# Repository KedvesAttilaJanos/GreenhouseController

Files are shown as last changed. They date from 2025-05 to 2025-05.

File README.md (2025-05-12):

# 🌱 Smart Greenhouse Controller (IoT Project)

📄 This README is available in multiple languages:
🇭🇺 [Magyarul itt olvasható »](docs/README.hu.md)

This project is a smart greenhouse controller built with Arduino and ESP8266 for monitoring and controlling various environmental factors in a greenhouse. The system collects data from multiple sensors and can be monitored remotely via a web interface.

## Features
- **Sensors:**
  - DHT11 – Temperature and Humidity Sensor
  - Soil Moisture Sensor (Analog output)
  - Light Sensor (LDR)
- **ESP8266 WiFi Module** – Enables remote monitoring via a web page.
- **OLED Display** – Displays real-time data on temperature, humidity, soil moisture, and light intensity.
- **Joystick** – Allows manual control for adjusting parameters such as watering or fan speed.
- **Future Plans** – Adding CO2 monitoring capabilities.

📄 Documentation
The full project documentation is available in two languages (Hungarian and English) in the /docs folder. It includes hardware schematics, system overview, and usage instructions.

## Components
- **Microcontroller:**
  - Arduino (for sensor data processing and control)
  - ESP8266 (for WiFi and web server)
  
- **Sensors:**
  - DHT11 – For temperature and humidity measurement
  - Soil Moisture Sensor – For soil moisture monitoring
  - Light Sensor (LDR) – For light intensity measurement
  
- **Display:**
  - OLED SSD1306 – For displaying sensor data
  
- **Joystick:**
  - Two-axis analog joystick for manual input
  
- **Libraries:**
  - `#include <SPI.h>` – For SPI communication
  - `#include <Wire.h>` – For I2C communication
  - `#include <Adafruit_GFX.h>` – For graphics on the display
  - `#include <dht.h>` – For DHT11/DHT22 sensor handling

## PCB and Schematics
The project includes a custom PCB designed for the greenhouse controller. You can find the PCB files and the circuit schematic below:
- **PCB Files**: The PCB layout files (Gerber) can be found in the `/hardware/` folder.
- **Schematic Diagram**: The circuit schematic for the project is available as [PDF](docs/Schematic.pdf) [SVG](docs/Schematic.svg).

**Wiring and Assembly**:
- The wiring diagram is available under `/docs/wiring_diagram.png`, which illustrates how to connect the sensors and the microcontroller.

## 3D Printed Case
The project includes a 3D printed case to house the controller and sensors. This case helps protect the electronics and provides a clean and durable solution for mounting the components.

- **3D Printing Files**: The STL files for the 3D printed case can be found in the `/3d_case/` folder.
- You can print the case using any 3D printer.
- **Print Settings**: The recommended print settings are:
  - Layer height: 0.2mm
  - Infill: 20-30%
  - Material: PLA or ABS

## Setup and Installation
1. **Install Arduino IDE**: If you haven’t already, install the [Arduino IDE](https://www.arduino.cc/en/software).
2. **Install Libraries**: 
   - Adafruit GFX: `Sketch > Include Library > Manage Libraries > Adafruit GFX`
   - DHT Sensor Library: `Sketch > Include Library > Manage Libraries > DHT sensor library`
   
3. **Wiring**:
   - Connect your sensors to the Arduino as per the wiring diagram. You can find the wiring diagram under `/docs/wiring_diagram.png`.

4. **Upload Code**:
   - Upload the code from `firmware/SmartGreenhouse.ino` to your Arduino using the Arduino IDE.

## Future Work
1. **Integration of Additional Modules**
    Add CO2 sensor to monitor air quality.
    Add I2C clock module, for time based irrigation

2. **Memory Optimization**  
   The system currently operates with redundant, repeated text outputs, such as on the OLED display. These text strings should be organized into static character arrays or `const char*` variables, reducing SRAM usage.

3. **Eliminating AT Commands**  
   The ESP8266 is currently controlled via AT commands, which is not the most efficient approach. Instead of using the AT firmware, it would be better to use the NodeMCU (Lua) or the ESP8266 Arduino core, programming the microcontroller directly. This would remove the need for AT commands over the serial connection, allowing the ESP8266 to handle the control directly, while the Arduino Mega only transmits sensor data. This improves response time, reduces the chance of errors, and opens up further possibilities (e.g., HTTPS connections, JSON handling). Right now, when the controller is communicating, the hardware interface is freezd for a sec.

4. **External Network Accessibility**  
   The system is currently only accessible on the local network. A future development could involve making the web interface accessible over the internet.

5. **Data Security and Encryption**  
   The transmitted data is likely unencrypted over the network, making encryption a critical feature to implement.

6. **Fault Tolerance and Diagnostics**  
   Implementing a basic fault-tolerant system would be useful, such as using a watchdog (same used in the restart method) timer that restarts the system if it freezes or if no data is received within a certain time period. A logging feature for save errors or key events to an SD card.
## License
This project is licensed under the [MIT License](LICENSE).
You are free to use, modify, and distribute this code, even in commercial projects, as long as you include the original license and credit the author.

## Contact
If you have any questions or suggestions, feel free to contact me at:  
ata.kedves@gmail.com

---

🌱 Happy gardening with your smart greenhouse!

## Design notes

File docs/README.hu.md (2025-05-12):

# 🌱 Okos Melegház Vezérlő (IoT Projekt)

Ez a projekt egy okos melegház vezérlő, amely Arduino és ESP8266 alapú, a különböző környezeti tényezők monitorozására és vezérlésére a melegházban. A rendszer több szenzortól gyűjt adatokat, és távolról, egy webes felületen keresztül figyelhető.

## Jellemzők
- **Szenzorok:**
  - DHT11 – Hőmérséklet- és páratartalom mérő
  - Talajnedvesség szenzor (analóg kimenet)
  - Fényérzékelő (LDR)
- **ESP8266 WiFi Modul** – Távoli monitorozás weboldalon keresztül.
- **OLED Képernyő** – Valós idejű adatok megjelenítése hőmérsékletről, páratartalomról, talajnedvességről és fényintenzitásról.
- **Joystick** – Manuális vezérlés a paraméterek, például öntözés vagy ventilátor sebességének beállításához.
- **Jövőbeli terveink** – CO2 monitorozási képességek hozzáadása.

📄 Dokumentáció  
A teljes projekt dokumentációja két nyelven (magyar és angol) elérhető a /docs mappában. Tartalmazza a hardver áramköri terveit, a rendszer áttekintését és a használati utasításokat.

## Alkatrészek
- **Mikrokontroller:**
  - Arduino (a szenzoradatok feldolgozásához és vezérléshez)
  - ESP8266 (WiFi és web szerverhez)

- **Szenzorok:**
  - DHT11 – A hőmérséklet és páratartalom méréséhez
  - Talajnedvesség szenzor – A talajnedvesség méréséhez
  - Fényérzékelő (LDR) – A fényintenzitás méréséhez

- **Képernyő:**
  - OLED SSD1306 – A szenzoradatok megjelenítéséhez

- **Joystick:**
  - Két tengelyes analóg joystick a manuális bemenethez

- **Könyvtárak:**
  - `#include <SPI.h>` – SPI kommunikációhoz
  - `#include <Wire.h>` – I2C kommunikációhoz
  - `#include <Adafruit_GFX.h>` – A képernyőn történő grafika megjelenítéséhez
  - `#include <dht.h>` – DHT11/DHT22 szenzor kezeléséhez

## PCB és Áramköri Tervek
A projekt tartalmaz egy egyedi PCB-t a melegház vezérlő számára. Az alábbiakban találhatóak a PCB fájlok és az áramköri terv:
- **PCB fájlok**: A PCB elrendezési fájlok (Gerber) a `/hardware/` mappában találhatók.
- **Áramköri diagram**: Az áramköri terv PDF formátumban elérhető: [PDF](Schematic.pdf) [SVG](Schematic.svg).

**Vezetékek és összeszerelés:**
- A vezetékek diagramja elérhető a `/docs/wiring_diagram.png` alatt, amely bemutatja, hogyan kell csatlakoztatni a szenzorokat és a mikrokontrollert.

## 3D Nyomtatott Tok
A projekt tartalmaz egy 3D nyomtatott tokot a vezérlő és a szenzorok elhelyezésére. Ez a tok segít megvédeni az elektronikát, és tiszta, tartós megoldást biztosít az alkatrészek felszereléséhez.

- **3D Nyomtatás Fájlok**: A 3D nyomtatott tok STL fájljai a `/3d_case/` mappában találhatók.
- A tok bármilyen 3D nyomtatóval kinyomtatható.
- **Nyomtatási beállítások**: A javasolt nyomtatási beállítások:
  - Rétegmagasság: 0.2mm
  - Kitöltés: 20-30%
  - Anyag: PLA vagy ABS

## Beállítás és Telepítés
1. **Arduino IDE telepítése**: Ha még nem tetted meg, telepítsd az [Arduino IDE-t](https://www.arduino.cc/en/software).
2. **Könyvtárak telepítése**: 
   - Adafruit GFX: `Sketch > Include Library > Manage Libraries > Adafruit GFX`
   - DHT szenzor könyvtár: `Sketch > Include Library > Manage Libraries > DHT sensor library`
   
3. **Vezetékek csatlakoztatása**:
   - Csatlakoztasd a szenzorokat az Arduinohoz a vezeték diagram szerint. A vezeték diagramot a `/docs/wiring_diagram.png` alatt találod.

4. **Kód feltöltése**:
   - Töltsd fel a kódot a `firmware/SmartGreenhouse.ino` fájlból az Arduino IDE segítségével.

## Jövőbeli Munka
1. **További modulok integrálása**
   CO2 szenzor hozzáadása a levegőminőség monitorozásához.
   I2C óra modul hozzáadása, idő alapú öntözéshez.

2. **Memória optimalizálás**  
   A rendszer jelenleg redundáns, ismétlődő szövegeket jelenít meg, például az OLED kijelzőn. Ezeket a szövegeket statikus karakter tömbökké vagy `const char*` változókká kell szervezni, csökkentve ezzel a SRAM használatot.

3. **AT parancsok eltávolítása**  
   Az ESP8266 jelenleg AT parancsokkal van vezérelve, ami nem a leghatékonyabb megoldás. Az AT firmware helyett jobb lenne a NodeMCU (Lua) vagy az ESP8266 Arduino alapú rendszer használata, közvetlenül a mikrokontroller programozásával. Ez eltávolítaná az AT parancsokat a soros kapcsolatról, lehetővé téve az ESP8266 számára, hogy közvetlenül végezze el a vezérlést, miközben az Arduino Mega csak az adatokat küldi. Ez javítja a válaszidőt, csökkenti a hibák lehetőségét, és további lehetőségeket nyit meg (pl. HTTPS kapcsolatok, JSON kezelés). Jelenleg, amikor a vezérlő kommunikál, a hardver interfész egy pillanatra lefagy.

4. **Külső hálózati elérhetőség**  
   A rendszer jelenleg csak a helyi hálózaton érhető el. A jövőben a webes felületet elérhetővé lehetne tenni az interneten.

5. **Adatbiztonság és titkosítás**  
   Az átadott adatok valószínűleg titkosítatlanok a hálózaton, így a titkosítás kritikus funkció lenne a megvalósítás során.

6. **Hibakeresés és diagnosztika**  
   Hasznos lenne egy alapvető hibatűrő rendszer bevezetése, például egy figyelő (watchdog) időzítő alkalmazása, amely újraindítja a rendszert, ha az lefagy, vagy ha egy meghatározott időn belül nem érkezik adat. Egy naplózó funkció, amely tárolja a hibákat vagy fontos eseményeket SD kártyán.

## Licenc
Ez a projekt a [MIT Licenc](/LICENSE) alatt van licencelve.  
Szabadon használhatod, módosíthatod és terjesztheted a kódot, még kereskedelmi projektekben is, amennyiben tartalmazza az eredeti licencet és tiszteletben tartja a szerző jogait.

## Kapcsolat
Ha bárminemű kérdésed vagy javaslatod van, bátran kereshetsz:
ata.kedves@gmail.com

---

🌱 Boldog kertészkedést az okos melegházaddal!

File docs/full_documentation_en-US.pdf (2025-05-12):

# Liceul Teoretic "Ernő Solomon" Gheorgheni

# Lucrare de atestat disciplina INFORMATICĂ

Profesor coordonator: | Elev:
Zoltán Csíki | Dear Attila-János

# Gheorgheni

2025

Subscribe to DeepL Pro to translate larger documents. Visit www.DeepL.com/pro (https://www.deepl.com/pro?cta=edit-document&pdf=1) for more information.

# Smart Greenhouse Controller

# -IoT project/Automated system-

## Content

# Introduction

### While thinking about my exam paper, I had several different project ideas. But I was sure that what I wanted to do should be useful and of some value. I wanted to create something that was not only interesting for me, but that could be used by

anyone else.

Automation is a technology that has been around for a long time, but I think that it is not available to everyone and that few people use it, especially in the agricultural sector, where it is possible to achieve great productivity results with simple automation. But if automation can be so useful, the question arises why it is not widespread. I think this question arises because these technologies are not explicitly available to individuals and only big-boned agricultural companies can

afford such improvements. In my view, open source projects can provide a solution.

### This will make it easier to bring the technology to users who have not had access to it

before.

### IoT, short for "Internet of things", is the English acronym for the Internet of

things. It short for a variety of electronic devices that can detect, possibly process, some essential information and communicate with another device on the network.

### This explains why it is important for an automated controller to belong to this IoT group. One of the main features of a greenhouse controller is that it can control the

current parameters even in the absence of the user, something an IoT device can do.

The main value of this system lies in the processing of sensory values. I designed it to be able to measure all the parameters that characterise a greenhouse. I considered humidity, temperature, ground humidity and light intensity to be less important, but I left the measurement of carbon dioxide levels as an extensible function. I considered it important to study the external temperature and humidity to

track how environmental factors affect the internal condition of the greenhouse.

### In addition to web-based management, it is important that the functions can be seen and modified on the spot. Monitoring is made possible by a 0.96 inch oled

display,

### which displays the data broken down into menu items. A joystick module allows you

to make changes.

### Of course, in addition to processing and managing data, it is essential to actively and artificially influence the internal environment. This is done by a 6-

channel relay module that switches on and off the light supply, humidification, irrigation and fan status.

### Ultimately, I think it is important to create automation systems that are

accessible to a wide range of users, both individuals and small businesses.

### Furthermore, it is also important that such an automation system is open source, so

that it can be understood by everyone and can be further developed in the future.

### From this point of view, I would like to recall an idea of Linus Torvalds: "Intelligence comes from the ability of people to use and develop the ideas of others."

# Development opportunities

The current greenhouse control system successfully implements the basic functions in many respects, such as temperature and humidity measurement and display on an OLED display, and the transmission of sensor data to an internal network server via the ESP8266 module. At the same time, the system can be further developed and optimised in several ways that not only increase performance, but also

significantly improve system reliability and functionality.

1. Memory optimisation In its current state, the system operates with redundant, repetitive text in several places, for example when writing to the OLED display. These text strings should be organized in static character arrays or in #define or const char* variables to reduce the load on SRAM. In addition, it is recommended to use C-style char[] arrays

instead of the String type, as the String type may fragment memory during long runs.

### 2. Omission of AT commands The ESP8266 is currently probably controlled via AT commands, which is not the most efficient solution. Instead of AT firmware, it is recommended to NodeMCU (Lua) or the ESP8266 Arduino core, and the microcontroller

### direct programming. This way, you don't need to send AT commands over a serial connection, but the ESP8266 itself takes control and the Arduino Mega only transmits sensor data. This increases response time, reduces error possibilities and extends the

possibilities (e.g. HTTPS connection, JSON handling).

### 3. Accessibility from an external network The system is currently only available on the internal network. A next development step could be to make the web interface available via the Internet. This can be achieved by using dynamic DNS (DDNS), port forwarding in the router, or - as

a more secure and scalable solution - by sending data to a cloud-based server (e.g.

### using MQTT, HTTPS POST REST API). The data can even be displayed in a real-

time web dashboard, e.g. Node-RED.

4. Data security and encryption Currently, the data being transmitted is likely to travel unencrypted over the network, so an important development is the introduction of encrypted data communication. This could be done using HTTPS or lower level AES encryption (either Arduino side encryption, server side decryption). This is particularly important

if the device is connected to the internet or would handle sensitive data in the future.

5. Modular and reusable code By structuring the project further, a more general, easily reusable code base can be created. It is advisable to organise the handling of individual hardware elements into separate classes or function groups (e.g. SHT sensor handler, display controller, network communication module). This not only makes the code more readable and maintainable, but also prepares the project for future expansion into a

multi-module system (e.g. multi-zone greenhouse).

### 6. Fault tolerance and diagnostics It would be useful to have a basic fault-tolerant system, for example using a watchdog timer, which restarts the system if it freezes or if no data is received for a certain period of time. In addition, a logging facility that saves errors or major events

to an SD card or the cloud is useful.

# Development environment

# Arduino IDE 2.0

### Programming an Arduino, like most programming languages, uses what is called an Integrated Development Environment, or IDE. An integrated development environment (IDE) is a software application that provides computer programmers with comprehensive facilities for software development. An IDE usually

consists of at least a source code editor, automation tools and a debugger.

### There are several IDEs to choose from for programming the arduino. Arduino officially offers two different Arduino IDEs for developers: Arduino IDE 1.x - This is the classic version, which was the default development

environment for a long time. It is simple, fast, and widely supported.

### Arduino IDE 2.x - The next generation Arduino IDE, offering a modern user interface, advanced editing features (e.g. auto-complete code, dark mode) and

improved debugging capabilities.

### I have chosen to develop with Arduino IDE 2.0, as this version provides a

more developer-friendly environment.

### This IDE provides easy debugging possibilities. A so-called serial monitor is available, which allows you to keep track of variables, runtime, and correct function

calls. This can be done by a simple Serial.print(Val, Format) line inserted in the code. Val - The data we want to print. It can be a number, string, character or variable.

### Format- This is an optional parameter that specifies the format in which the value

should be displayed.

### Overview of arduino IDE 2

### (1) Error correction (2) Upload, upload the program to for microcontroller (3) Check/debug

### (1.) Managing files in use (2.) Motherboard manager, installing different motherboards (3.) Library manager, installing libraries (4.) Debugging, debugger (5.) Search by keyword in the project

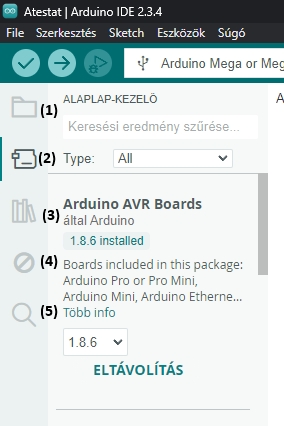
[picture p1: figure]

# Version control

Version management is the management of data with multiple versions.

### Version management systems are most commonly used in engineering and software development to manage versions of documents under development, designs, source code and other data that multiple people are working on simultaneously. Each change

is tracked by version numbers or version letters.

Version Control Systems (VCS) are software tools that allow you to track changes to program code or other digital files over time. During software development, the source code is constantly changing: new features are added, bugs are fixed, or experimental changes are made by developers. A well-functioning version control system allows these changes to be documented and retrieved, and allows multiple developers to work on the same project at the same time without

accidentally overwriting each other's work.

With version management, all changes are logged: who changed what, when and what. This not only makes development more transparent and secure, but also allows you to restore a stable state to a previous state if, for example, a new change causes a bug. Version management not only supports teamwork, but also organises

and archives the work of individual developers.

The best-known and most widely used version control system today is Git,

developed by Linus Torvalds, the creator of the Linux operating system. Git is a distributed version control system, so each developer has the history of the entire project on his own machine. This is particularly useful when you are temporarily disconnected from the Internet or need to back up. The most popular online repository for Git is GitHub, which not only allows version control, but also offers a full community platform where other developers' projects are available and you can

collaborate.

# Libraries

### The development of an efficient and fast

we use different libraries for programming.

The term "library" simply refers to a file that contains compiled object code (and data) that can later be edited (linked) by a program. Libraries allow an application to be more modular, faster to recompile and easier to update. Libraries can be classified into three types: static libraries, shared libraries and dynamic load (DL)

libraries.

### In the Arduino ecosystem, libraries can be installed via the built-in interface and can be included in code with a single #include statement. Each library is used to

support a specific hardware or function, for example.
- #include <Wire.h> - Handles I2C (Inter-Integrated Circuit) communication.

### - #include <Adafruit_GFX.h> - The Adafruit Graphics Library, which draws

graphical objects (text, lines, shapes) on the display.

### - #include <dht.h> - A simple library for managing DHT11/DHT22 temperature and

humidity sensors.

# Tools

### For the project, I used various hardware tools to provide control, data collection and display. These devices work together to implement the functionality of

the system.

## Microcontroller: Arduino and ESP8266

### The project is based on an Arduino Mega, which is responsible for managing the sensors and displays. In addition, the ESP8266 Wi-Fi module allows the system to

connect to a network and send data to a server.

## Arduino Mega

### The Arduino microcontroller processes the sensor data and controls the output

devices.

### The Arduino Mega 2560 is an ATmega2560 microcontroller board. It has 54 digital input and output pins (15 of which can be used as PWM outputs), 16 analog

inputs, 4 UART (hardware serial port), 16 MHz crystal oscillator, USB connector, power connector, ICSP header and reset button.

### Structure of the arduino mega

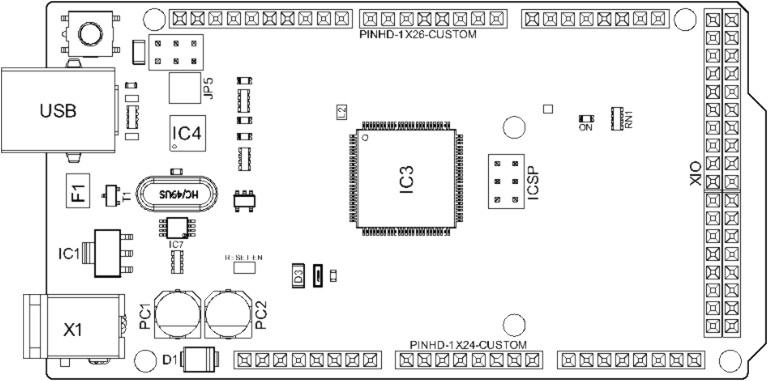
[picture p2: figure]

### Footprint of the arduino mega

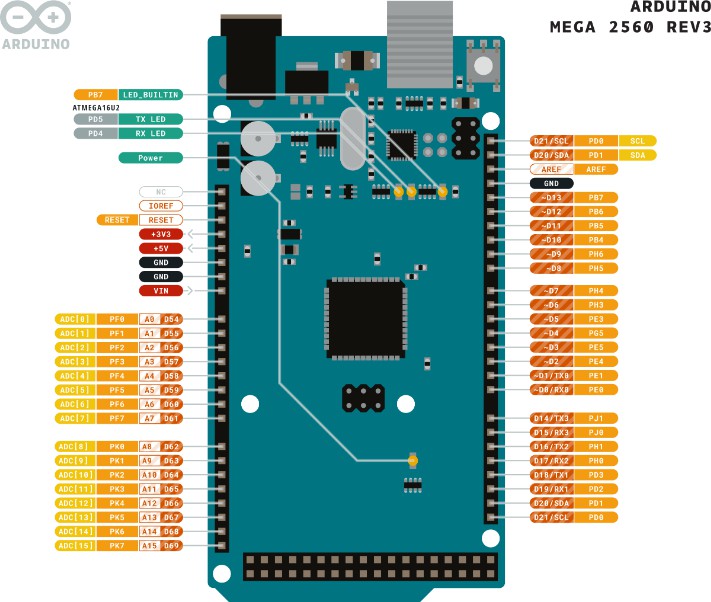
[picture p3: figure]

## ESP8266:

A microcontroller that can also act as a standalone Wi-Fi module,

### communicating with the Arduino via AT commands over a serial connection and

allowing data to be transmitted to the Internet.

The ESP8266 is a very popular, low-cost Wi-Fi enabled microcontroller module developed by Espressif Systems. The module has an integrated TCP/IP protocol stack and a 32-bit RISC CPU that can operate at clock speeds of up to 80-160 MHz. Thanks to its built-in Wi-Fi functionality, it is an ideal choice for IoT (Internet of Things) projects, as it can connect to wireless networks independently or act as a Wi-Fi

modem in addition to another microcontroller.

The ESP-01 has only 8 legs, two of which can be used as GPIO ports (GPIO0, GPIO2), the rest for power, serial communication (TX/RX) and control.
It can be programmed with AT commands via another microcontroller (e.g.

### Arduino UNO) or directly if a suitable USB to serial converter and the appropriate

firmware in the Arduino IDE are available.
The figure below shows the function of the microcontroller's pins (Figure 1) and an example of how to connect it to an arduino mega (Figure 2).

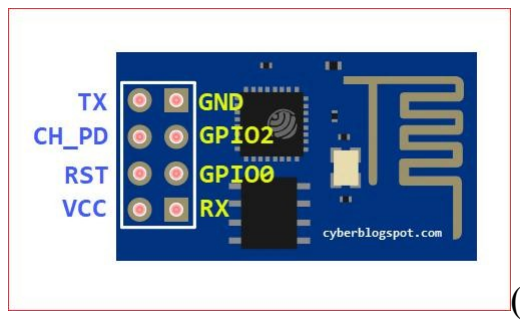
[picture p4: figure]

(Figure 1.)

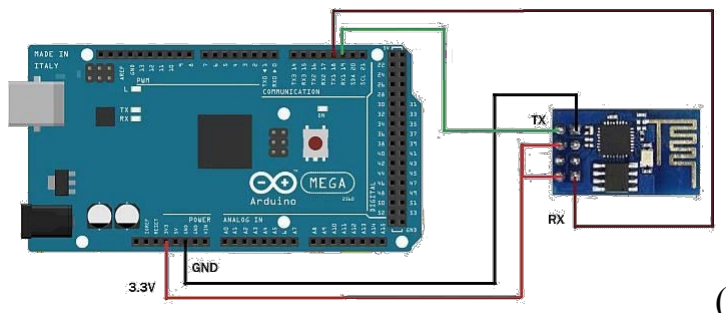
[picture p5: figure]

### (Figure 2,)

## Sensors (sensors)

### To operate the system, I used various sensors that allow the measurement and

processing of environmental data.

### DHT11 - Temperature and humidity sensor

- It allows you to measure air temperature and humidity.
- It provides digital output that can be easily processed by the Arduino.

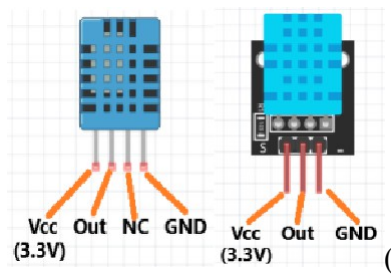
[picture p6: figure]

### (Output of the sensor spikes)

### Soil moisture sensor

### - It measures the soil moisture content, which can help to control

automatic irrigation.

### - It gives an analog output, which can be received by one of the analog pins of the

arduino.

(Function of the sensor spikes)

### Light level detector LDR

- Photo-resistance, the amount of resistance depends on the intensity of the light incident on it.
- The output is read by one of the analog inputs of the arduino.

## Display: OLED SSD1306

### The 0.96-inch OLED display (SSD1306) allows you to visualize the

measured data in menu-driven format.Using the Adafruit SSD1306 and GFX libraries, you can easily plot text and graphical elements (e.g. icons or diagrams).

The SSD1306 type display using OLED (Organic Light Emitting Diode) technology is a low-power, high-contrast display often used in embedded systems such as Arduino or ESP8266 microcontrollers. The most common version of the display is 0.96 inches in diameter, has a resolution of 128x64 pixels, and contains a control chip, SSD1306, which is responsible for driving the OLED matrix. This controller also supports I2C and SPI communication protocols, allowing easy

connectivity and fast data transfer.

### Displays have the advantage of a high brightness, high contrast image, as each pixel light independently, eliminating the need for backlighting. Their small size and low power consumption make them ideal for mobile and IoT applications such as

displaying sensor data or simple menus.

The following figures show the connections needed to communicate with the Arduino. The first figure (Figure 1) shows a connection established with an arduino uno using the I2C communication protocol. The second figure (Figure 2) shows the function of the display spikes (also using I2C communication protocol). The third figure (Figure 3) also shows the function of the spikes, but with a display using SCA

communication.

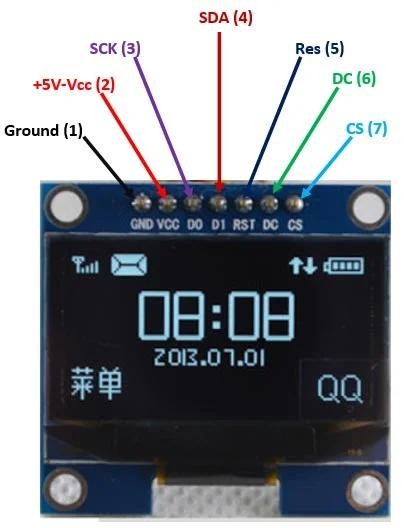
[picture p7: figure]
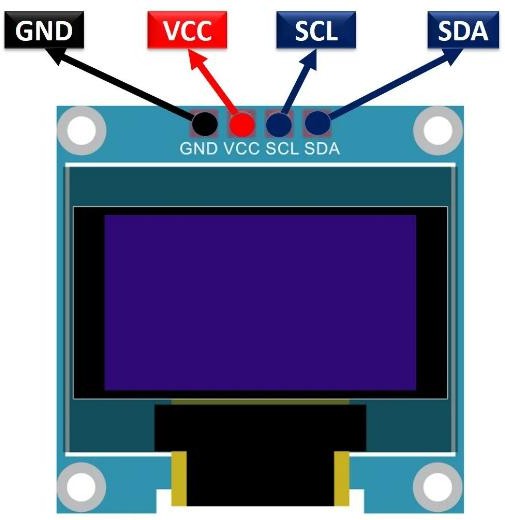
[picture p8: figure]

Figure 3. | Figure 2.

Figure 1.

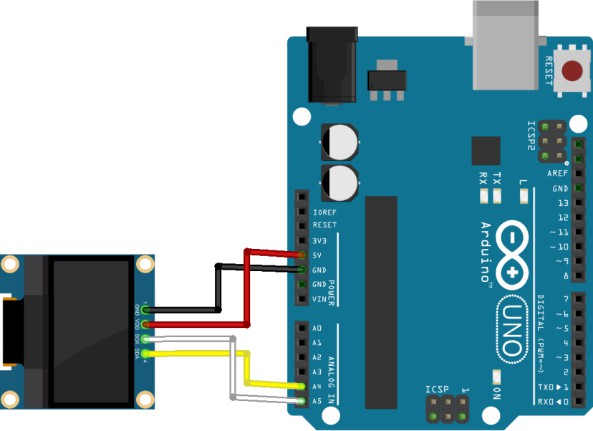
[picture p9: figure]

## Joystick module

## - In this project I use a two-axis analogue joystick module, which allows the

user to provide physical input to the system.

## - This module consists of two potentiometers and a push button, so it can

detect X-Y movement and click.

## The following pictures show the connectors of the module and the values

returned in relation to the displacement.

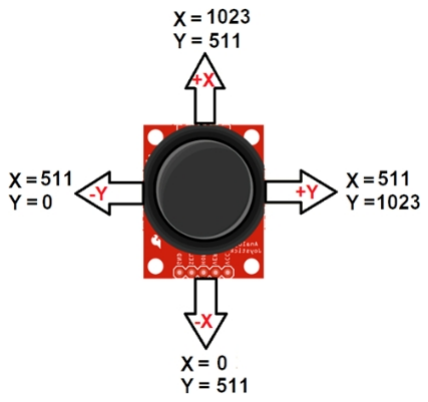
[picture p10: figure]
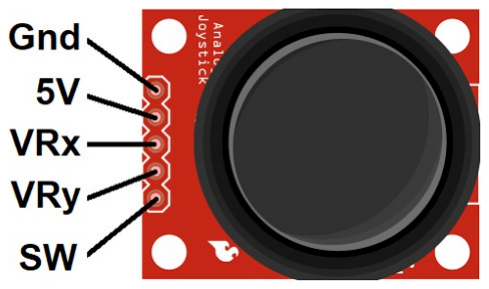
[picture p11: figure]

# Protocols

### In the project, I use different communication protocols to transfer data between devices. These protocols allow sensors, displays and the ESP8266 Wi-Fi

module to communicate with the Arduino.

## 1. I²C (Inter-Integrated Circuit) protocol

- I²C is a serial communication protocol mainly used to connect sensors,

### displays and other peripherals. It is a two-wire system consisting of a clock

line (SCL) and a data line (SDA).

### - I²C is typically used for short-range, relatively low-speed communication between ICs and on-board systems - The I²C (Inter-Integrated Circuit) is a multi-master, multi-slave, packet-switched serial bus developed by Philips Semiconductor (now NXP

Semiconductors).

### - In this project, the I2C protocol is used to communicate with the display, but as a development option it can be extended with an RTC module to monitor

the time in real time.

### Illustration of the I2C protocol

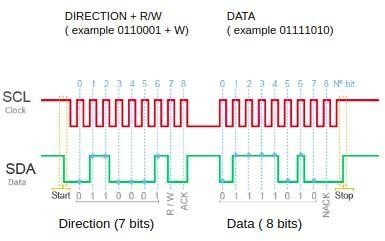
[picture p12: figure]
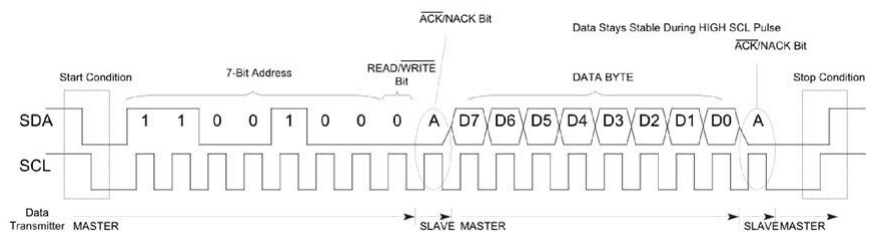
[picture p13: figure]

## 2. UART (Universal Asynchronous Receiver-Transmitter) -

### Soros communication - A universal asynchronous transceiver (UART for short) is a hardware device

that translates between serial and parallel interfaces.

### - The UART protocol is one of the most commonly used communication methods between microcontrollers and external modules. It is based on two wire systems: TX-Transmitter - Transmitter, RX-Receiver - Receiver - In my project the arduino and the esp8266 are connected in series

### The UART protocol diagram

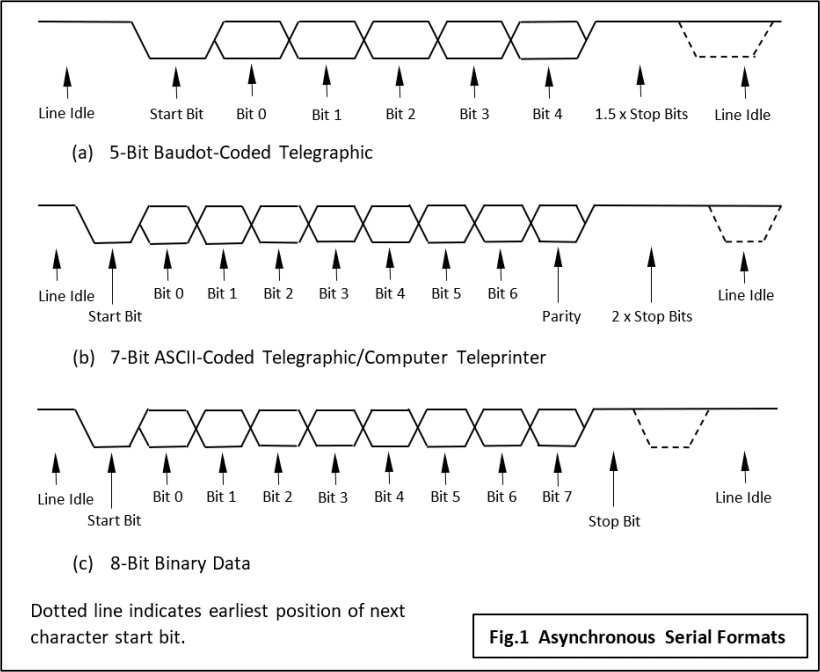
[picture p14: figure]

### 3. AT protocol - The protocol allows a microcontroller or computer to issue instructions to a

device, such as an ESP8266 Wi-Fi module, via serial (UART) communication.

### - AT-Commands (or Hayes AT-Commands) is a standard modem controller command set originally developed by Hayes Microcomputer Products in the 1980s. The abbreviation "AT" is derived from the word "attention", since each command begins with the prefix "AT", indicating to the modem that a

new command is about to follow.

### - Examples of using at commands with esp: - AT+CWJAP="SSID", "PASSWORD" - Connect to Wi-Fi network

(ESP8266).
- Retrieve AT+CIFSR-Ip cim.

### - AT+CIPSTART="TCP","192.168.1.50",8080-szerverhez való

joining.

# Used programming environment

To implement the project I used the Arduino programming language, which is based on C and C++, but has a simplified syntax.

I relied on Arduino's native functions, such as: 1. pinMode(pin, mode) Set a given digital leg as input (INPUT), output (OUTPUT), or input with an internal pull-up resistor (INPUT_PULLUP). Specific example: - pinMode(13, OUTPUT); // set D13 as output (e.g. for LED control) - pinMode(2, INPUT); // set D2 foot as input (e.g. for button)

- pinMode(3, INPUT_PULLUP); // | D3 input, internal | pull-up

### resistor 2. digitalWrite(pin, value) Sends a signal to a digital output (HIGH or LOW). A concrete example: - digitalWrite(13, HIGH); // Turns on the LED connected to D13 - digitalWrite(13, LOW); // Turns off the LED connected to D13 3. digitalRead(pin)

Reads the status (HIGH or LOW) of a digital input.

### 4. analogWrite(pin, value) It generates a PWM (Pulse Width ) signal at the specified output. The value

can be between 0 and 255. Only works on PWM-enabled legs.

### Concrete example: analogWrite(9, 128); // PWM signal on D9 with 50% fill factor 5. analogRead(pin)

Reads the value of an analog input between 0 and 1023.

### Concrete example: int Temperature = analogRead(A0); // Read the voltage of leg A0 (0-1023) 6. delay(ms) Stops the program running for a specified millisecond (ms). Concrete example: delay(1000); // 1 second delay 7. millis()

Returns the time in milliseconds since the program was started. Concrete example: unsigned long inditasotaElteltIdo = millis();

### 8. map(value, fromLow, fromHigh, toLow, toHigh) Scales a number one range to another. Concrete

example: int sensor = analogRead(A0);
int scaled to= map(sensor, 0, 1023, 0, 255);

# System design and wiring diagrams

# Overview

The purpose of the system is to monitor and control the environmental parameters of the greenhouse.The arduino receives the data from the sensors and controls the relle module based on the parameters. The arduino communicates with the esp8266 wifi module to send the data. The arduino controls the oled display via I2C communication. The joystick module gives user input control through two analog

inputs and a digital one through a button.

# Wiring Diagram

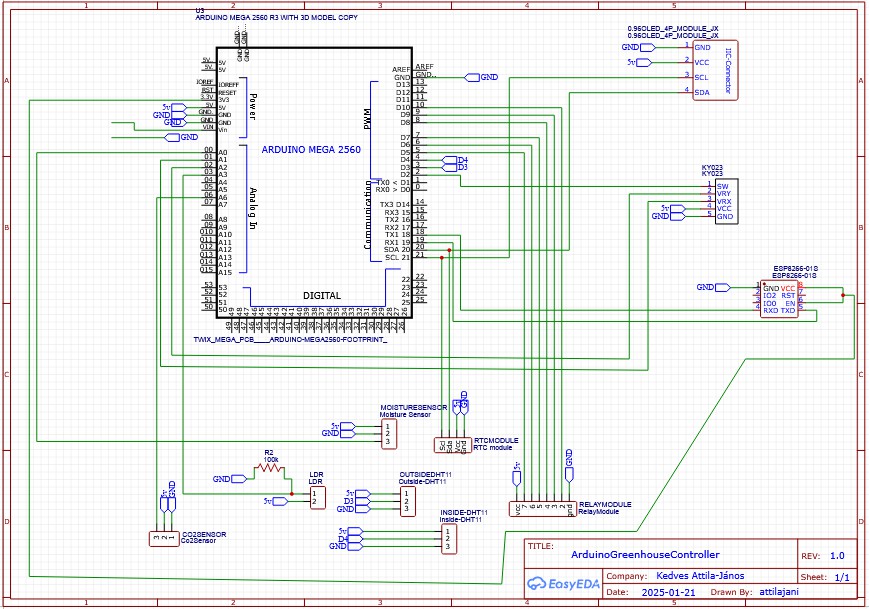
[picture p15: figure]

# Circuit

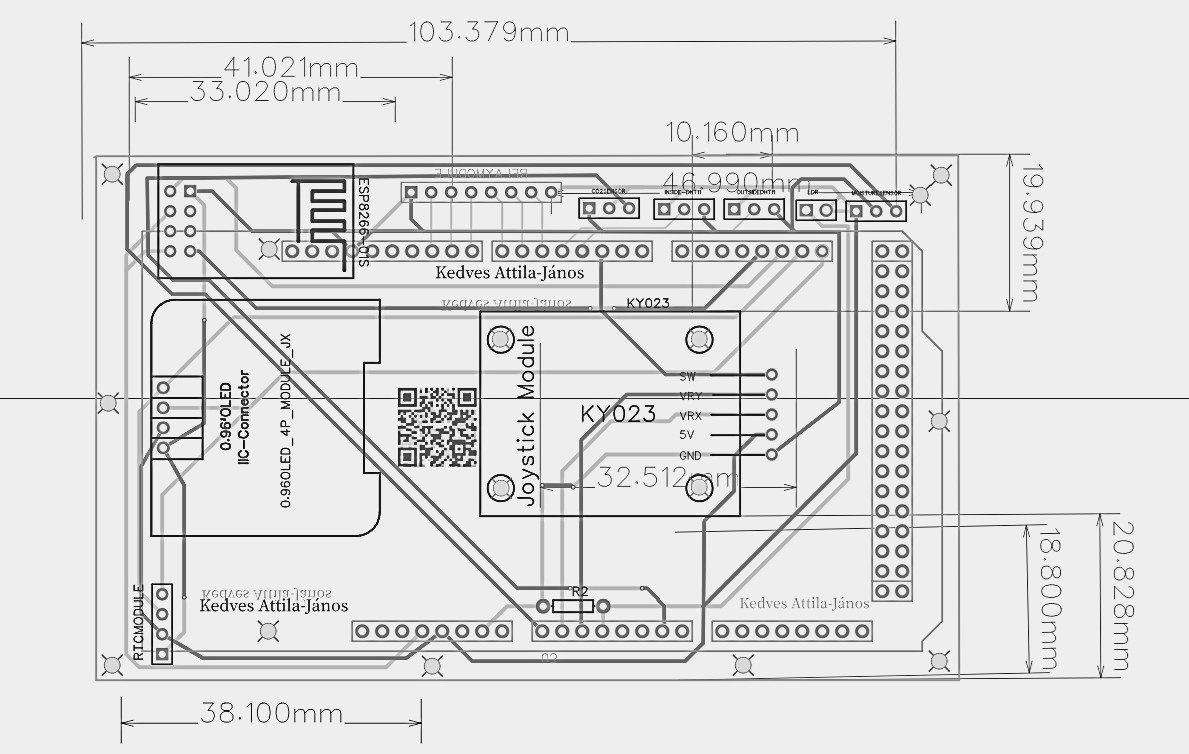
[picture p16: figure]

# Binding table

Arduino Mega 2560 Pin | Connected Device | Type of connection Comment
3V ESP8266 | Food supply | Voltage
Serial1 TX A1 A2 A3 A6 SDA (A4) SCL (A5) | ESP8266 RX Joystick module X-axis Joystick module Y-axis Light sensor C02 sensor OLED display, I2C module OLED display, I2C module | Soros communications Analogue input Analogue input Analogue input Analogue input I2C communication Dateline I2C communication Watchline | ESP RX - Mega TX X Movement Y movement Photosensitive resistance Carbon dioxide level
5V | Multiple modules (e.g. OLED, DHT) | Food supply | Voltage
GND | More modules (all) | Earthing | Common GND
D2 | Push button | Digital input | Gomb
D3 | DHT11 | Digital input | Temperature/humidity
D4 | DHT11 | Digital input | Temperature/humidity
D5-D10 | Relay module | Digital output | Relay control
Serial1 RX | ESP8266 TX | Soros communications | ESP TX - Mega RX

# The finished controller

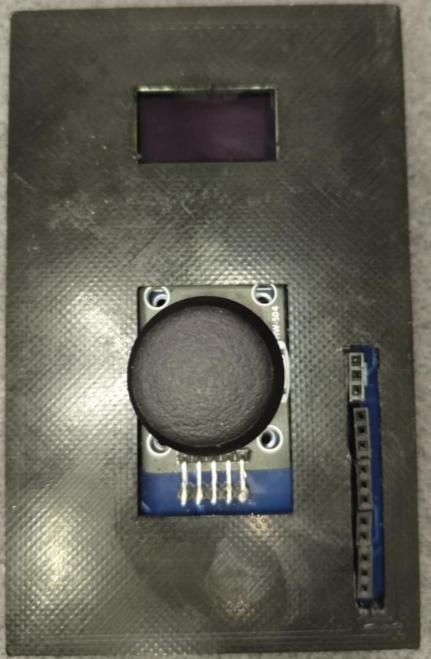
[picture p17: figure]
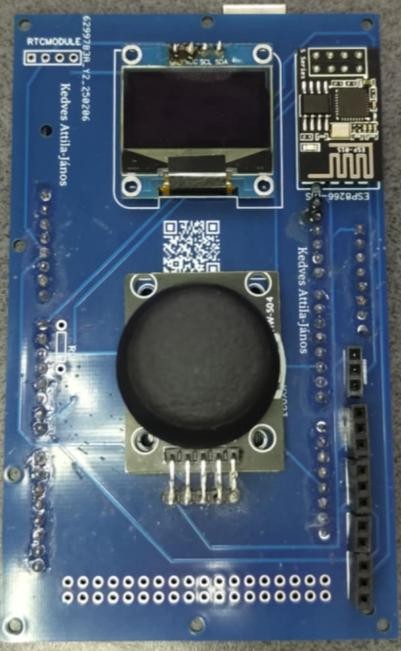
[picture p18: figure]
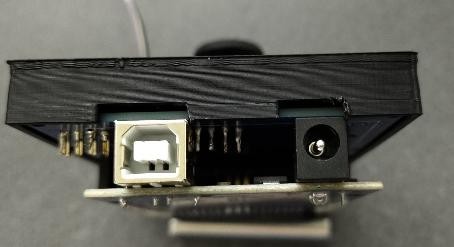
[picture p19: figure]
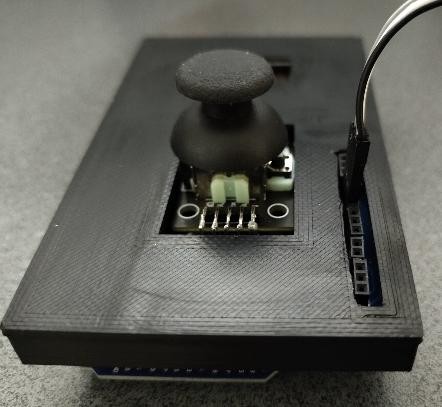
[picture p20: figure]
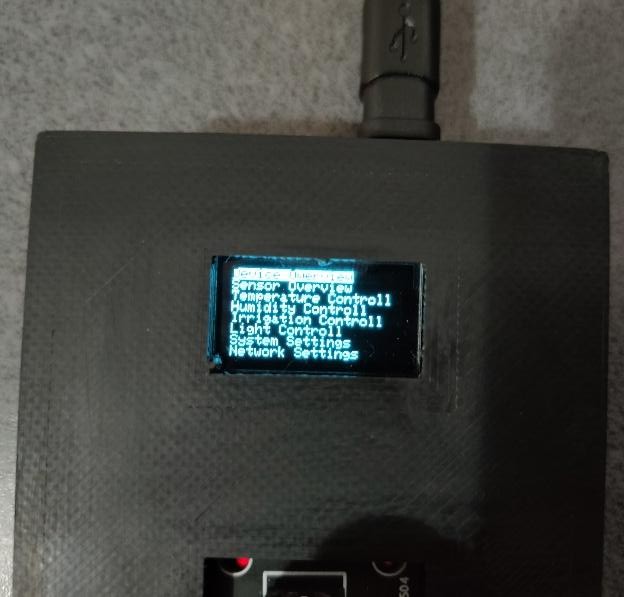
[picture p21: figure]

# Source code

1. //Add used libraries
2. #include <SPI.h>
3. #include <Wire.h>
4. #include <Adafruit_GFX.h>
5. #include <Adafruit_SSD1306.h>
6. #include <dht.h>
7. #include <SoftwareSerial.h>
8. #include <Vector.h>
9. #include <avr/wdt.h>
10.
11. //Specify the connected spikes of the devices and the constant values and declare the objects to be used
12. //Temp and humidity
13. #define dht1 3
14. #define dht2 4
15. // Declaration of the two DHT sensor objects
16. dht DHT1;
17. dht DHT2;
18. //Moisture sensor
19. #define MOISTURESENSOR A0
20. #define MINMOISTURE 500
21. #define MAXMOISTURE 180
22. //Output relays
23. #define FANPIN 7
24. #define IRRIGATIONPIN 8
25. #define SPRAYPIN 9
26. #define HEATERPIN 10
27. #define LIGHTPIN 6
28. // Declaration of oled display with i2c communication
29. #define SCREEN_WIDTH 128
30. #define SCREEN_HEIGHT 64
31. #define OLED_RESET -1
32. #define SSD1306_I2C_ADDRESS 0x3C
33. Adafruit_SSD1306 display(SCREEN_WIDTH, SCREEN_HEIGHT, &Wire, OLED_RESET); 34.
35. //joystick
36. #define JOYSTICK_X A1
37. #define JOYSTICK_Y A2
38. #define JOYSTICK_BUTTON 2
39. #define JOYSTICK_MAXTRESHOLD 900
40. #define JOYSTICK_MINTRESHOLD 100
41.
42. #define MAX_MENU_COUNT 7 // the menu items are indexed from 0, so this is 1 to less
43. #define MIN_CHANGE_SPEED 0
44. #define MAX_CHANGE_SPEED 100
45. #define SERIALPRINTINTERVAL 5000
46. #define DEBUG 0
47. #define NETWORKTYPE 0 //0-STA, 1 AP
48. #define SERIALNUMBER 123456
49. #define WIFINAME "DIGI_57c120"
50. #define PASSWORD "195da83e"
51. #define AITHINKER "AI-THINKER_394EDC"
52. // Declaring input and output variables:
53. // Input variables (sensor data):
54. byte insideTemperature, outsideTemperature, insideHumidity, outsideHumidity, soilMoistureLevel, lightIntensity;
55. // Output variables (controlled devices):
56. enum DeviceState
57. {
58. | OFF, | // 0
59. | ON, | // 1
60. AUTO // 2

61. };
62. DeviceState fanState, irrigationState, sprayState, heaterState, lightState; 63.
64. //Declare internal variables:
65. //wifi
66. | String ssid= String(WIFINAME); | // Name of the wifi AI-THINKER_394EDC
67. | String password= String(PASSWORD); | // Password for the wifi network
68. String ipAddress= "";
69. int joystickAxisX, joystickAxisY; //A axis-related assignments to the joystick
70. bool joystickButtonState;
71. byte currentMenuNumber;
72. byte currentSubmenuNumber;
73. byte maxMenuCount;
74. bool isSubMenu;
75. long long lastTimeMenuRefresh;
76. // Button's time elapsed test
77. const byte menuChangeInterval= 500; // menu/submenu valtozas
78. long long lastTimeChange= 0;// Check the time elapsed between Left/Right position
79. long long lastTimeSerial= 0;
80. const char deviceStateStrings[3][4]= {"OFF", "ON", "AUTO"}; // for the quickest
way to select the quickest way to select the device
81. Declare //Min and max target variables:
82. byte maxTemp, minTemp, maxHumidity, minHumidity, maxMoisture, minMoisture, minLightLevel;
83. const char* languages[3]= {"Eng", "Hun", "Ro"};
84. byte languageSet;
85. bool enableSerial= DEBUG;
86. bool networkType= NETWORKTYPE;
87. byte changeSpeed= 20;
88. byte connectionId;
89. //Save main menu values in flash memory
90. const char menu1[] PROGMEM= "Device Owerview";
91. const char menu2[] PROGMEM= "Sensor Overview";
92. const char menu3[] PROGMEM= "Temperature Control";
93. const char menu4[] PROGMEM= "Humidity Control";
94. const char menu5[] PROGMEM= "Irrigation Control";
95. const char menu6[] PROGMEM= "Light Control";
96. const char menu7[] PROGMEM= "System Settings";
97. const char menu8[] PROGMEM= "Network Settings";
98. const char* const messages[] = {menu1,menu2,menu3,menu4,menu5,menu6,menu7,menu8};
99. //Guidelines
100. void readSensor()//Read values measured by sensors
101. {
102. int insideSensor= DHT1.read11(dht1);
103. insideTemperature= DHT1.temperature;
104. insideHumidity= DHT1.humidity;
105. int outsideSensor= DHT2.read11(dht2);
106. outsideTemperature= DHT2.temperature;
107. outsideHumidity= DHT2.humidity;
108. soilMoistureLevel= map(analogRead(MOISTURESENSOR), MINMOISTURE, MAXMOISTURE, 0, 100);
109. }
110.
111. void restartArduino() // restart the arduino
112. {
113. wdt_enable(WDTO_15MS); // Enable watchdog for 15ms
114. | while (1); | // Wait for restart/Freeze the program
115. }
116. void espSetup() // initialize the esp
117. {
118. sendData("AT+RST\r\n",2000,enableSerial); // reset module
119. if(networkType)
120. {
121. ssid= String(AITHINKER);
122. password= "-";
123. sendData("AT+CWMODE=2\r\n",1000,enableSerial); // configure as access point

124. }
125. else
126. {
127. ssid= String(WIFINAME);
128. password= String(PASSWORD);
129. delay(1000); // a little extra waiting
130. //configure as station mode, connect to wifi
131. sendData("AT+CWMODE=1\r\n", 1000, enableSerial);
132. // Connect to wifi (ssid+password)
133. String connectCommand= "AT+CWJAP=\""+ ssid+ "\",\""+ password+ "\"\r\n";
134. sendData(connectCommand, 8000, enableSerial);
135. }
136. sendData("AT+CIPMUX=1\r\n",1000,enableSerial); // configure for multiple connections
137. sendData("AT+CIPSERVER=1,80\r\n",1000,enableSerial); // turn on server on port 80
138. }
139. void getIp() // Get the ip address
140. {
141. delay(1000);
142. // Get IP address
143. ipAddress= sendData("AT+CIFSR\r\n", 1000, enableSerial);
144. byte first= ipAddress.indexOf(''');
145. byte second= ipAddress.indexOf('"', first+ 1);
146. if (first != -1 && second != -1)
147. {
148. ipAddress= ipAddress.substring(first+ 1, second);
149. } else
150. {
151. Serial.println("ip error");
152. }
153. }
154. String booleanStateOnOff(bool state) // return bool as string for ejection
155. {
156. if(state)
157. return "On";
158. else
159. return "Off";
160. }
161. String sendData(String command, const int timeout, boolean debug) //Commands send to the esp and receive its reply
162. {
163. String response= "";
164. Serial1.print(command);
165. long int time= millis();
166. while( (time+ timeout)> millis())
167. {
168. while(Serial1.available())
169. {
170. char c= Serial1.read(); // read the next character.
171. response+= c;
172. }
173. }
174. if(debug)
175. {
176. Serial.print(response); //displays the esp response messages in arduino Serial monitor
177. }
178. return response;
179. }
180. void espsend(String date) //Set up and execute the espsend command
181. {
182. String cipSend= " AT+CIPSEND=";
183. cipSend+= connectionId;
184. cipSend+= ",";
185. cipSend+= date.length();
186. cipSend+= "\r\n";
187. sendData(cipSend,1000,enableSerial);
188. sendData(date,1000,enableSerial);

189. }
190. void showMessageOnScreen(String message) // Show text in the middle of the display
191. {
192. display.clearDisplay();
193. | display.setTextSize(1); | // Set text size
194. display.setTextColor(WHITE);
195. | display.setCursor(0, 10); | // Set text position
196. display.println(message);
197. display.display();
198. }
199. void transmitDateOnEsp(String data)// Handle communication with esp
200. {
201. if(Serial1.available())
202. {
203. if(Serial1.find("+IPD,")) //watch for request arrival
204. {
205. showMessageOnScreen("Network communication\nin progress...");
206. delay(300);
207. connectionId= Serial1.read()-48;
208. String webpage= data;
209. webpage+= connectionId;
210. espsend(webpage);
211. }
212. String closeCommand= "AT+CIPCLOSE="; ////////////////close the socket connection////esp command
213. closeCommand+= connectionId; // append connection id
214. closeCommand+= "\r\n";
215. sendData(closeCommand,3000,enableSerial);
216. }
217. }
218. String constructDateString() //A Construct a string sent to the network based on the controller data
219. {
220. String dataString= "InTemp="+ String(insideTemperature)+ "&OutTemp="+ String(outsideTemperature)+ "&InHum="+ String(insideHumidity)+ "&OutHum="+ String(outsideHumidity)+ "&Moi="+ String(soilMoistureLevel)+ "&Light="+ String(lightIntensity)+ "&maxTemp="+ String(maxTemp)+ "&minTemp="+ String(minTemp)+ "&maxHum="+ String(maxHumidity)+ "&minHum="+ String(minHumidity)+ "&maxMoi="+ String(maxMoisture) ;
221. dataString+= "&minMoisture="+ String(minMoisture)+ "&minLightLevel="+ String(minLightLevel)+"&fanState="+ String(fanState)+ "&irrigationState="+ String(irrigationState)+ "&sprayState="+ String(sprayState)+ "&heaterState="+ String(heaterState) + "&lightState=" + String(lightState);
222. String html= "<!DOCTYPE html><html><html><head><meta http-equiv=\\\"refresh\\\\\" content=\\\\"5\\\\"><title>Greenhouse"+ String(SERIALNUMBER)+ "</title></head><body>"+ dataString+ "</body></html>";
223.
224. return html;
225. }
226. void outRelays() // Turn on and off the relay modules based on their stateminLightLevel
227. {
228. if(heaterState== 2)
229. {
230. if(insideTemperature< minTemp)
231. digitalWrite(HEATERPIN, HIGH);
232. if(insideTemperature >(minTemp+ maxTemp)/2)
233. digitalWrite(HEATERPIN, LOW);
234. }
235. if (heaterState== 1)
236. digitalWrite(HEATERPIN, HIGH);
237. if (heaterState== 0)
238. digitalWrite(HEATERPIN, LOW);
239. if(fanState== 2)
240. {
241. if(insideTemperature > maxTemp)
242. digitalWrite(FANPIN, HIGH);
243. if(insideTemperature< (minTemp+ maxTemp)/2)
244. digitalWrite(FANPIN, LOW);
245. }

246. if(fanState== 1)
247. digitalWrite(FANPIN, HIGH);
248. if(fanState== 0)
249. digitalWrite(FANPIN, LOW);
250. if(irrigationState== 2)
251. {
252. if(soilMoistureLevel < minMoisture)
253. digitalWrite(IRRIGATIONPIN, HIGH);
254. if(soilMoistureLevel > maxMoisture)
255. digitalWrite(IRRIGATIONPIN, LOW);
256. }
257. if(irrigationState== 1)
258. digitalWrite(IRRIGATIONPIN, HIGH);
259. if(irrigationState== 0)
260. digitalWrite(IRRIGATIONPIN, LOW);
261. if(lightState== 2)
262. {
263. if(lightIntensity < minLightLevel)
264. digitalWrite(LIGHTPIN, HIGH);
265. if(lightIntensity>= minLightLevel)
266. digitalWrite(LIGHTPIN,LOW);
267. }
268. if(lightState== 1)
269. digitalWrite(LIGHTPIN, HIGH);
270. if(lightState== 0)
271. digitalWrite(LIGHTPIN, LOW);
272. switch (sprayState)
273. {
274. case 0:digitalWrite(SPRAYPIN, LOW);break;
275. case 1:digitalWrite(SPRAYPIN, HIGH);break;
276. case 2:
277. if(insideHumidity< minHumidity)
278. digitalWrite(SPRAYPIN, HIGH);
279. if(insideHumidity> (minHumidity+ maxHumidity)/2)
280. digitalWrite(SPRAYPIN, LOW);
281. break;
282. }
283.
284. }
285. short languageChooser (short currentLanguage)// Change the language chooser default
286. {
287. if (joystickAxisY> JOYSTICK_MAXTRESHOLD)
288. {
289. currentLanguage ++;
290. if(currentLanguage> 2)
291. currentLanguage= 0;
292. }
293. else
294. {
295. if (joystickAxisY< JOYSTICK_MINTRESHOLD)
296. {
297. currentLanguage --;
298. if(currentLanguage< 0)
299. currentLanguage= 2;
300.
301. }
302.
303. }
304. delay(changeSpeed+ 100);
305. return currentLanguage;
306. }
307. void changeSubmenuBoolean(bool &booleanToChange)// Change the bool menu variable, based on joystickAxisY
308. {
309. if (joystickAxisY> JOYSTICK_MAXTRESHOLD|| joystickAxisY< JOYSTICK_MINTRESHOLD)
310. {
311. booleanToChange= !booleanToChange;
312. }

313. delay(changeSpeed+ 30);
314. }
315. short changeSubmenuVariable(short numberToChange) // Change the number values in the submenus
316. {
317.
318. if (joystickAxisY> JOYSTICK_MAXTRESHOLD)
319. {
320. numberToChange++;
321. }
322. else
323. {
324. if (joystickAxisY< JOYSTICK_MINTRESHOLD)
325. {
326. numberToChange--;
327. }
328. }
329. delay(changeSpeed+ 30);
330. return numberToChange;
331.
332. }
333. DeviceState changeDeviceState(DeviceState deviceState)// Change the device state
334. {
335. short counter= deviceState;
336.
337. if (joystickAxisY> JOYSTICK_MAXTRESHOLD)
338. {
339. counter ++;
340. if(counter> 2)
341. counter= 0;
342. }
343. else
344. {
345. if (joystickAxisY< JOYSTICK_MINTRESHOLD)
346. {
347. counter --;
348. if(counter< 0)
349. counter= 2;
350. }
351. else return static_cast< DeviceState>(counter);
352. }
353. delay(changeSpeed+ 100);
354. return static_cast< DeviceState>(counter);
355. }
356. void changeMenuNumber(bool isSubMenu, byte maxNumber)// Increase/decrease the value of the menu and submenu
357. {
358. if(millis()-lastTimeMenuRefresh> changeSpeed+ 50)//Test the time between changes for correct operation
359. {
360. lastTimeMenuRefresh= millis();
361. if(isSubMenu) // if(isSubMenu) // whether to change the value of the main menu or the submenu
362. {
363. if (joystickAxisX> JOYSTICK_MAXTRESHOLD)
364. {
365. if(maxNumber> currentSubmenuNumber)
366. currentSubmenuNumber++;
367. else
368. currentSubmenuNumber= 0;
369.
370. }
371. else
372. {
373. if (joystickAxisX< JOYSTICK_MINTRESHOLD)
374. {
375. if(currentSubmenuNumber> 0)
376. currentSubmenuNumber--;
377. else

378. currentSubmenuNumber= maxNumber; 379.
380. }
381. }
382. }
383. else
384. {
385. if (joystickAxisX> JOYSTICK_MAXTRESHOLD)
386. {
387. if(maxNumber> currentMenuNumber)
388. currentMenuNumber++;
389. else
390. currentMenuNumber= 0;
391.
392. }
393. else
394. {
395. if (joystickAxisX< JOYSTICK_MINTRESHOLD)
396. {
397. if(currentMenuNumber> 0)
398. currentMenuNumber--;
399. else
400. currentMenuNumber= maxNumber; 401.
402. }
403. }
404. }
405. }
406. }
407. void readJoystickValues()// Read the state of the joystick module
408. {
409. joystickAxisX= 1024-analogRead(JOYSTICK_X);
410. joystickAxisY = analogRead(JOYSTICK_Y);
411. joystickButtonState= !digitalRead(JOYSTICK_BUTTON); 412.}
413. void serialMonitorPrint() // Print data serially for reading
414. {
415. if(millis()-lastTimeSerial > SERIALPRINTINTERVAL)
416. {
417. lastTimeSerial= millis();
418. Serial.println();
419. Serial.println(millis());
420. Serial.print(F("Output variables:")); // F() is required because SRAM is corrupted, so it loads the Flash memory
421. Serial.print(F(" fanState: "));
422. Serial.print(fanState);
423. Serial.print(F(" irrigationState: "));
424. Serial.print(irrigationState);
425. Serial.print(F(" sprayState: "));
426. Serial.print(sprayState);
427. Serial.print(F(" fanState: "));
428. Serial.print(fanState);
429. Serial.print(F(" lightState: "));
430. Serial.println(lightState);
431. Serial.println();
432. Serial.print(F("Sensor values: "));
433. Serial.print(F(" insideTemperature: "));
434. Serial.print(insideTemperature);
435. Serial.print(F(" outsideTemperature: "));
436. Serial.print(outsideTemperature);
437. Serial.print(F(" insideHumidity: "));
438. Serial.print(insideHumidity);
439. Serial.print(F(" outsideHumidity: "));
440. Serial.print(outsideHumidity);
441. Serial.print(F(" soilMoistureLevel: "));
442. Serial.print(soilMoistureLevel);
443. Serial.print(F(" lightIntensity: "));
444. Serial.println(lightIntensity);
445. Serial.println();
446. Serial.print(F("Joystick values: "));

447. Serial.print(F(" joystickAxisX: "));
448. Serial.print(joystickAxisX);
449. Serial.print(F(" joystickAxisY: "));
450. Serial.print(joystickAxisY);
451. Serial.print(F(" joystickButtonState: "));
452. Serial.println(joystickButtonState);
453. Serial.println();
454. Serial.print(F("Menu value: "));
455. Serial.print(currentMenuNumber);
456. Serial.print(F("Submenu value: "));
457. Serial.print(currentSubmenuNumber);
458. Serial.print(F("isSubmenu: "));
459. Serial.print(isSubMenu);
460. | Serial.println("\n | ");
461.
462. }
463.
464. }
465. void killAllDevices()//Set all devices to OFF, and disable all relays
466. {
467. //set the device state to off
468. fanState= OFF;
469. irrigationState= OFF;
470. sprayState= OFF;
471. heaterState= OFF;
472. lightState= OFF;
473. //give the command to the rells
474. digitalWrite(FANPIN, LOW);
475. digitalWrite(IRRIGATIONPIN, LOW);
476. digitalWrite(SPRAYPIN, LOW);
477. digitalWrite(HEATERPIN, LOW);
478. digitalWrite(LIGHTPIN, LOW);
479. }
480. void displayInitialize()//Display the home screen
481. {
482. if(!display.begin(SSD1306_SWITCHCAPVCC, SSD1306_I2C_ADDRESS)) {
483. Serial.println(F("SSD1306 allocation failed"));
484. for(;;); // Failed to establish connection, infinite loop
485. }
486. display.clearDisplay();// Clear the buffer
487.
488. | display.setTextSize(1); | // Set text size
489. display.setTextColor(WHITE);
490. | display.setCursor(0, 0); | // Set text position
491. display.println(F("Dear Attila Janos"));
492. display.println("Github:");
493. display.println(F("https://github.com/KedvesAttilaJanos"));
494. display.display();
495. delay(5000);
496. showLoadingScreen();
497. }
498. void loaderSwitch(byte loadNum) // Determine the execution order of setup tasks according to the loading screen
499. {
500. switch(loadNum)
501. {
502. case 30: espSetup(); Serial.println(F("Esp setuped")); break;
503. case 50: getIp(); Serial.println(F("Ip get")); break;
504. case 60: killAllDevices(); Serial.println(F("Devices off")); break;
505. case 70: zeroAllSensor(); Serial.println(F("Sensors Zero")); break;
506. case 80: zeroAllInternalVariable(); Serial.println(F("Internal variables zero")); break;
507. case 90: readSensor(); Serial.println(F("First read")); break;
508. }
509. }
510. bool joystickAxisYMoved(String direction) //overload, you can specify as parameter which direction to look at the joystick movement
511. {
512. if(direction== "right")
513. return joystickAxisY > JOYSTICK_MAXTRESHOLD;

514. if(direction== "left")
515. return joystickAxisY < JOYSTICK_MINTRESHOLD;
516. }
517. bool joystickAxisYMoved() // Monitor left/right movement
518. {
519. return joystickAxisY< JOYSTICK_MINTRESHOLD|| joystickAxisY> JOYSTICK_MAXTRESHOLD;
520. }
521. void showLoadingScreen()//Show Loading Screen
522. {
523. display.clearDisplay();
524. | display.setTextSize(1); | // Set text size
525. display.setTextColor(WHITE);
526. | display.setCursor(10, 10); | // Set text position
527. display.println(F("Loading..."));
528. display.display();
529.
530. // Animation loading bar
531. for (int i= 0; i<= 100; i+= 2) {
532. display.fillRect(10, 30, i, 10, WHITE); // Draw a bar
533. loaderSwitch(i);
534. display.display();
535. delay(2); // lane refresh rate
536. }
537.
538. // Clear or next screen
539. delay(500);
540. display.clearDisplay();
541. display.display();
542. }
543. void zeroAllSensor()//Reset all sensor values to zero
544. {
545. insideTemperature= 0;
546. outsideTemperature= 0;
547. insideHumidity= 0;
548. outsideHumidity= 0;
549. soilMoistureLevel= 0;
550. lightIntensity= 0;
551. }
552. void zeroAllInternalVariable()// Reset all internal variables
553. {
554. joystickAxisX= 0;
555. joystickAxisY= 0;
556. joystickButtonState= 0;
557. isSubMenu= false;
558. currentMenuNumber= 0;
559. currentSubmenuNumber= -1;
560. lastTimeMenuRefresh= 0;
561. maxMenuCount= MAX_MENU_COUNT;
562. maxTemp= 0;
563. minTemp= 0;
564. maxHumidity= 0;
565. minHumidity= 0;
566. maxMoisture= 0;
567. minMoisture= 0;
568. minLightLevel= 0;
569. languageSet= 0;
570. enableSerial= DEBUG;
571. }
572. void printCentered(const String &text, int y)// Print centered addresses
573. {
574. int textWidth= text.length() * 6; // 6 pixel wide characters
575. int x= (SCREEN_WIDTH - textWidth) / 2;
576. display.setCursor(x, y);
577. display.println(text);
578. }
579. void changeSelectedMenuVariable()// Change the selected values
580. {
581. if(isSubMenu)
582. {

583. switch (currentMenuNumber)
584. {
585. case 0:
586. if (currentSubmenuNumber== 0) fanState= changeDeviceState(fanState);
587. if (currentSubmenuNumber== 1) irrigationState= changeDeviceState(irrigationState);
588. if (currentSubmenuNumber== 2) sprayState= changeDeviceState(sprayState);
589. if (currentSubmenuNumber== 3) heaterState= changeDeviceState(heaterState);
590. if (currentSubmenuNumber== 4) lightState= changeDeviceState(lightState);
591. break;
592. }
593. }
594. }
595. void mainMenuSystem()// Display menus, with decisions to display the menu item with background
596. {
597. display.setTextSize(1);
598. display.clearDisplay();
599. short devices[5] {fanState, irrigationState, sprayState, heaterState, lightState};
600. if(!isSubMenu) //Check if you are in submenu or main menu
601. {
602. display.setTextColor(WHITE);
603. display.setCursor(0,0);
604. char buffer[20]; // This is where we load from PROGMEM
605. for (size_t i= 0; i< 8; i++)
606. {
607. strcpy_P(buffer, (char*)pgm_read_word(&(messages[i])));
608. if (currentMenuNumber== i)
609. display.setTextColor(BLACK,WHITE);
610. else
611. display.setTextColor(WHITE);
612. display.println(buffer);
613. }
614. display.display();
615.
616. }
617. else
618. {
619. switch(currentMenuNumber)
620. {
621. case 0:
622. maxMenuCount= 4;
623. switch(currentSubmenuNumber)
624. {
625. case 0:
626. printCentered(F("Device Overview"),0);
627. display.setTextColor(BLACK,WHITE);
628. | display.print(F("Fan State | "));
629. display.println(deviceStateStrings[fanState]);
630. display.setTextColor(WHITE);
631. display.print(F("Irrigation State "));
632. display.println(deviceStateStrings[irrigationState]);
633. | display.print(F("Spray State | "));
634. display.println(deviceStateStrings[sprayState]);
635. | display.print(F("Heater State | "));
636. display.println(deviceStateStrings[heaterState]);
637. | display.print(F("Light State | "));
638. display.println(deviceStateStrings[lightState]);
639. display.display();
640. fanState= changeDeviceState(fanState);
641. break;
642. case 1:
643. printCentered(F("Device Overview"),0);
644. | display.print(F("Fan State | "));
645. display.println(deviceStateStrings[fanState]);
646. display.setTextColor(BLACK,WHITE);
647. display.print(F("Irrigation State "));
648. display.println(deviceStateStrings[irrigationState]);

649. display.setTextColor(WHITE);
650. | display.print(F("Spray State | "));
651. display.println(deviceStateStrings[sprayState]);
652. | display.print(F("Heater State | "));
653. display.println(deviceStateStrings[heaterState]);
654. | display.print(F("Light State | "));
655. display.println(deviceStateStrings[lightState]);
656. display.display();
657. irrigationState= changeDeviceState(irrigationState);
658. break;
659. case 2:
660. printCentered(F("Device Overview"),0);
661. | display.print(F("Fan State | "));
662. display.println(deviceStateStrings[fanState]);
663. display.print(F("Irrigation State "));
664. display.println(deviceStateStrings[irrigationState]);
665. display.setTextColor(BLACK,WHITE);
666. | display.print(F("Spray State | "));
667. display.println(deviceStateStrings[sprayState]);
668. display.setTextColor(WHITE);
669. | display.print(F("Heater State | "));
670. display.println(deviceStateStrings[heaterState]);
671. | display.print(F("Light State | "));
672. display.println(deviceStateStrings[lightState]);
673. display.display();
674. sprayState= changeDeviceState(sprayState);
675. break;
676. case 3:
677. printCentered(F("Device Overview"),0);
678. | display.print(F("Fan State | "));
679. display.println(deviceStateStrings[fanState]);
680. display.print(F("Irrigation State "));
681. display.println(deviceStateStrings[irrigationState]);
682. | display.print(F("Spray State | "));
683. display.println(deviceStateStrings[sprayState]);
684. display.setTextColor(BLACK,WHITE);
685. | display.print(F("Heater State | "));
686. display.println(deviceStateStrings[heaterState]);
687. display.setTextColor(WHITE);
688. | display.print(F("Light State | "));
689. display.println(deviceStateStrings[lightState]);
690. display.display();
691. heaterState= changeDeviceState(heaterState);
692. break;
693. case 4:
694. printCentered(F("Device Overview"),0);
695. | display.print(F("Fan State | "));
696. display.println(deviceStateStrings[fanState]);
697. display.print(F("Irrigation State "));
698. display.println(deviceStateStrings[irrigationState]);
699. | display.print(F("Spray State | "));
700. display.println(deviceStateStrings[sprayState]);
701. | display.print(F("Heater State | "));
702. display.println(deviceStateStrings[heaterState]);
703. display.setTextColor(BLACK,WHITE);
704. | display.print(F("Light State | "));
705. display.println(deviceStateStrings[lightState]);
706. display.setTextColor(WHITE);
707. display.display();
708. lightState= changeDeviceState(lightState);
709. break;
710.
711. }
712. break;
713. case 1:
714. printCentered(F("Sensor Overview "),0);
715. | display.print(F("Inside Temp. | "));
716. display.println(insideTemperature);
717. display.print(F("Outside Temp. "));
718. display.println(outsideTemperature);

719. display.print(F("Inside Humidity "));
720. display.println(insideHumidity);
721. display.print(F("Outside Humidity"));
722. display.println(outsideHumidity);
723. display.print(F("Soil Moisture "));
724. display.println(soilMoistureLevel);
725. | display.print(F("Light Level | "));
726. display.println(lightIntensity);
727. display.display();
728. break;
729. case 2:
730. maxMenuCount= 3;
731. switch(currentSubmenuNumber)
732. {
733. case 0:
734. printCentered(F("Temp Controll"),0);
735. display.setTextColor(BLACK,WHITE);
736. | display.print(F("Max Temp | "));
737. display.println(maxTemp);
738. display.setTextColor(WHITE);
739. | display.print(F("Min Temp | "));
740. display.println(minTemp);
741. | display.print(F("Fan State | "));
742. display.println(deviceStateStrings[fanState]);
743. | display.print(F("Heater State | "));
744. display.println(deviceStateStrings[heaterState]);
745. | display.print(F("Inside Temp | "));
746. display.println(insideTemperature);
747. | display.print(F("Outside Temp | "));
748. display.println(outsideTemperature);
749. display.display();
750. maxTemp = changeSubmenuVariable(maxTemp);
751. break;
752. case 1:
753. printCentered(F("Temp Controll"),0);
754. | display.print(F("Max Temp | "));
755. display.println(maxTemp);
756. display.setTextColor(BLACK,WHITE);
757. | display.print(F("Min Temp | "));
758. display.println(minTemp);
759. display.setTextColor(WHITE);
760. | display.print(F("Fan State | "));
761. display.println(deviceStateStrings[fanState]);
762. | display.print(F("Heater State | "));
763. display.println(deviceStateStrings[heaterState]);
764. | display.print(F("Inside Temp | "));
765. display.println(insideTemperature);
766. | display.print(F("Outside Temp | "));
767. display.println(outsideTemperature);
768. display.display();
769. minTemp = changeSubmenuVariable(minTemp);
770. break;
771. case 2:
772. printCentered(F("Temp Controll"),0);
773. | display.print(F("Max Temp | "));
774. display.println(maxTemp);
775. | display.print(F("Min Temp | "));
776. display.println(minTemp);
777. display.setTextColor(BLACK,WHITE);
778. | display.print(F("Fan State | "));
779. display.println(deviceStateStrings[fanState]);
780. display.setTextColor(WHITE);
781. | display.print(F("Heater State | "));
782. display.println(deviceStateStrings[heaterState]);
783. | display.print(F("Inside Temp | "));
784. display.println(insideTemperature);
785. | display.print(F("Outside Temp | "));
786. display.println(outsideTemperature);
787. display.display();
788. fanState= changeDeviceState(fanState);

789. break;
790. case 3:
791. printCentered(F("Temp Controll"),0);
792. | display.print(F("Max Temp | "));
793. display.println(maxTemp);
794. | display.print(F("Min Temp | "));
795. display.println(minTemp);
796. | display.print(F("Fan State | "));
797. display.println(deviceStateStrings[fanState]);
798. display.setTextColor(BLACK,WHITE);
799. | display.print(F("Heater State | "));
800. display.println(deviceStateStrings[heaterState]);
801. display.setTextColor(WHITE);
802. | display.print(F("Inside Temp | "));
803. display.println(insideTemperature);
804. | display.print(F("Outside Temp | "));
805. display.println(outsideTemperature);
806. display.display();
807. heaterState= changeDeviceState(heaterState);
808. break;
809. }
810.
811. break;
812. case 3:
813. maxMenuCount= 2;
814. switch(currentSubmenuNumber)
815. {
816. case 0:
817. printCentered(F("Humidity Control"),0);
818. display.setTextColor(BLACK,WHITE);
819. | display.print(F("Max Humidity | "));
820. display.println(maxHumidity);
821. display.setTextColor(WHITE);
822. | display.print(F("Min Humidity | "));
823. display.println(minHumidity);
824. | display.print(F("Spray State | "));
825. display.println(deviceStateStrings[sprayState]);
826. display.print(F("Inside Humidity "));
827. display.println(insideHumidity);
828. display.print(F("Outside Humidity "));
829. display.println(outsideHumidity);
830. display.display();
831. maxHumidity= changeSubmenuVariable(maxHumidity);
832. break;
833. case 1:
834. printCentered(F("Humidity Control"),0);
835. | display.print(F("Max Humidity | "));
836. display.println(maxHumidity);
837. display.setTextColor(BLACK,WHITE);
838. | display.print(F("Min Humidity | "));
839. display.println(minHumidity);
840. display.setTextColor(WHITE);
841. | display.print(F("Spray State | "));
842. display.println(deviceStateStrings[sprayState]);
843. display.print(F("Inside Humidity "));
844. display.println(insideHumidity);
845. display.print(F("Outside Humidity "));
846. display.println(outsideHumidity);
847. display.display();
848. minHumidity= changeSubmenuVariable(minHumidity);
849. break;
850. case 2:
851. printCentered(F("Humidity Control"),0);
852. | display.print(F("Max Humidity | "));
853. display.println(maxHumidity);
854. | display.print(F("Min Humidity | "));
855. display.println(minHumidity);
856. display.setTextColor(BLACK,WHITE);
857. | display.print(F("Spray State | "));
858. display.println(deviceStateStrings[sprayState]);

859. display.setTextColor(WHITE);
860. display.print(F("Inside Humidity "));
861. display.println(insideHumidity);
862. display.print(F("Outside Humidity "));
863. display.println(outsideHumidity);
864. display.display();
865. sprayState= changeDeviceState(sprayState);
866. break;
867. }
868. break;
869. case 4:
870. maxMenuCount= 2;
871. switch(currentSubmenuNumber)
872. {
873. case 0:
874. printCentered(F("Irrigation Controll"),0);
875. display.setTextColor(BLACK,WHITE);
876. | display.print(F("Max Moisture | "));
877. display.println(maxMoisture);
878. display.setTextColor(WHITE);
879. | display.print(F("Min Moisture | "));
880. display.println(minMoisture);
881. display.print(F("Irrigation State "));
882. display.println(deviceStateStrings[irrigationState]);
883. | display.print(F("Moisture Level | "));
884. display.println(soilMoistureLevel);
885. display.display();
886. maxMoisture= changeSubmenuVariable(maxMoisture);
887. break;
888. case 1:
889. printCentered(F("Irrigation Controll"),0);
890. | display.print(F("Max Moisture | "));
891. display.println(maxMoisture);
892. display.setTextColor(BLACK,WHITE);
893. | display.print(F("Min Moisture | "));
894. display.println(minMoisture);
895. display.setTextColor(WHITE);
896. display.print(F("Irrigation State "));
897. display.println(deviceStateStrings[irrigationState]);
898. | display.print(F("Moisture Level | "));
899. display.println(soilMoistureLevel);
900. display.display();
901. minMoisture= changeSubmenuVariable(minMoisture);
902. break;
903. case 2:
904. printCentered(F("Irrigation Controll"),0);
905. | display.print(F("Max Moisture | "));
906. display.println(maxMoisture);
907. | display.print(F("Min Moisture | "));
908. display.println(minMoisture);
909. display.setTextColor(BLACK,WHITE);
910. display.print(F("Irrigation State "));
911. display.println(deviceStateStrings[irrigationState]);
912. display.setTextColor(WHITE);
913. | display.print(F("Moisture Level | "));
914. display.println(soilMoistureLevel);
915. display.display();
916. irrigationState= changeDeviceState(irrigationState);
917. break;
918. }
919. break;
920. case 5:
921. maxMenuCount= 1;
922. switch(currentSubmenuNumber)
923. {
924. case 0:
925. printCentered(F("Light Control"),0);
926. display.setTextColor(BLACK,WHITE);
927. display.print(F("Min Light Level: "));
928. display.println(minLightLevel);

929. display.setTextColor(WHITE);
930. | display.print(F("Ligth State | "));
931. display.println(deviceStateStrings[lightState]);
932. display.print(F("Ligth Intensity "));
933. display.println(lightIntensity);
934. display.display();
935. minLightLevel= changeSubmenuVariable(minLightLevel);
936. break;
937. case 1:
938. printCentered(F("Light Control"),0);
939. display.print(F("Min Light Level: "));
940. display.println(minLightLevel);
941. display.setTextColor(BLACK,WHITE);
942. | display.print(F("Ligth State | "));
943. display.println(deviceStateStrings[lightState]);
944. display.setTextColor(WHITE);
945. display.print(F("Ligth Intensity "));
946. display.println(lightIntensity);
947. display.display();
948. lightState= changeDeviceState(lightState);
949. break;
950.
951. }
952. break;
953. case 6:
954. maxMenuCount= 5;
955. switch(currentSubmenuNumber)
956. {
957. case 0:
958. printCentered(F("System Setting"),0);
959. display.setTextColor(BLACK,WHITE);
960. display.println(F("Restart Sensors "));
961. display.setTextColor(WHITE);
962. display.println(F("Restart Devices "));
963. | display.print(F("Language | "));
964. display.println(languages[languageSet]);
965. | display.print(F("Enable Serial | "));
966. display.println(booleanStateOnOff(enableSerial));
967. display.print(F("Change Slowenes "));
968. display.println(changeSpeed);
969. display.println(F("Restart Arduino "));
970. display.print(F("Name: "));
971. display.print(SERIALNUMBER);
972. display.display();
973. if(joystickAxisYMoved())
974. {
975. zeroAllSensor();
976. display.clearDisplay();
977. printCentered(F("Sensors Restarted"),16);
978. display.display();
979. delay(500);
980. }
981. break;
982. case 1:
983. printCentered(F("System Setting"),0);
984. display.println(F("Restart Sensors "));
985. display.setTextColor(BLACK,WHITE);
986. display.println(F("Restart Devices "));
987. display.setTextColor(WHITE);
988. | display.print(F("Language | "));
989. display.println(languages[languageSet]);
990. | display.print(F("Enable Serial | "));
991. display.println(booleanStateOnOff(enableSerial));
992. display.print(F("Change Slowenes "));
993. display.println(changeSpeed);
994. display.println(F("Restart Arduino "));
995. display.print(F("Name: "));
996. display.print(SERIALNUMBER);
997. display.display();
998. if(joystickAxisYMoved("left"))

999. {
1000. | killAllDevices();
1001. | display.clearDisplay();
1002. | printCentered(F("Devices Restarted"),16);
1003. | display.display();
1004. | delay(500);
1005. | }
1006. | break;
1007. | case 2:
1008. | printCentered(F("System Setting"),0);
1009. | display.println(F("Restart Sensors "));
1010. | display.println(F("Restart Devices "));
1011. | display.setTextColor(BLACK,WHITE);
1012. | display.print(F("Language | "));
1013. | display.println(languages[languageSet]);
1014. | display.setTextColor(WHITE);
1015. | display.print(F("Enable Serial | "));
1016. | display.println(booleanStateOnOff(enableSerial));
1017. | display.print(F("Change Slowenes "));
1018. | display.println(changeSpeed);
1019. | display.println(F("Restart Arduino "));
1020. | display.print(F("Name: "));
1021. | display.print(SERIALNUMBER);
1022. | display.display();
1023. | languageSet= languageChooser(languageSet);
1024. | break;
1025. | case 3:
1026. | printCentered(F("System Setting"),0);
1027. | display.println(F("Restart Sensors "));
1028. | display.println(F("Restart Devices "));
1029. | display.print(F("Language | "));
1030. | display.println(languages[languageSet]);
1031. | display.setTextColor(BLACK,WHITE);
1032. | display.print(F("Enable Serial | "));
1033. | display.println(booleanStateOnOff(enableSerial));
1034. | display.setTextColor(WHITE);
1035. | display.print(F("Change Slowenes "));
1036. | display.println(changeSpeed);
1037. | display.println(F("Restart Arduino "));
1038. | display.print(F("Name: "));
1039. | display.print(SERIALNUMBER);
1040. | display.display();
1041. | changeSubmenuBoolean(enableSerial);
1042. | break;
1043. | case 4:
1044. | printCentered(F("System Setting"),0);
1045. | display.println(F("Restart Sensors "));
1046. | display.println(F("Restart Devices "));
1047. | display.print(F("Language | "));
1048. | display.println(languages[languageSet]);
1049. | display.print(F("Enable Serial | "));
1050. | display.println(booleanStateOnOff(enableSerial));
1051. | display.setTextColor(BLACK,WHITE);
1052. | display.print(F("Change Slowenes "));
1053. | display.println(changeSpeed);
1054. | display.setTextColor(WHITE);
1055. | display.println(F("Restart Arduino "));
1056. | display.print(F("Name: "));
1057. | display.print(SERIALNUMBER);
1058. | display.display();
1059. | changeSpeed= changeSubmenuVariable(changeSpeed);
1060. | if(changeSpeed<= MIN_CHANGE_SPEED)
1061. | {
1062. | changeSpeed= MAX_CHANGE_SPEED;
1063. | }
1064. | else if(changeSpeed> MAX_CHANGE_SPEED)
1065. | {
1066. | changeSpeed= MIN_CHANGE_SPEED;
1067. | }
1068. | break;

1069. | case 5:
1070. | printCentered(F("System Setting"),0);
1071. | display.println(F("Restart Sensors "));
1072. | display.println(F("Restart Devices "));
1073. | display.print(F("Language | "));
1074. | display.println(languages[languageSet]);
1075. | display.print(F("Enable Serial | "));
1076. | display.println(booleanStateOnOff(enableSerial));
1077. | display.print(F("Change Slowenes "));
1078. | display.println(changeSpeed);
1079. | display.setTextColor(BLACK,WHITE);
1080. | display.println(F("Restart Arduino "));
1081. | display.setTextColor(WHITE);
1082. | display.print(F("Name: "));
1083. | display.print(SERIALNUMBER);
1084. | display.display();
1085. | if(joystickAxisYMoved())
1086. | {
1087. | showMessageOnScreen("Arduino restarting");
1088. | restartArduino();
1089. | }
1090.
1091. | break;
1092. | }
1093. | break;
1094. | case 7:
1095. | maxMenuCount= 1;
1096. | printCentered(F("Network Settings"),0);
1097. | switch (currentSubmenuNumber)
1098. | {
1099. | case 0:
1100. | display.setTextColor(BLACK,WHITE);
1101. | display.println(F("Left for reset"));
1102. | if(joystickAxisY > JOYSTICK_MAXTRESHOLD)
1103. | {
1104. | display.clearDisplay();
1105. | printCentered(F("Network restarting"),16);
1106. | display.display();
1107. | espSetup();
1108. | getIp();
1109. | display.clearDisplay();
1110. | printCentered(F("Network restarted"),16);
1111. | display.display();
1112. | Serial.println(F("Esp restarted"));
1113. | delay(500);
1114. | }
1115. | display.setTextColor(WHITE);
1116. | display.print("Operation mode: ");
1117. | if(networkType)
1118. | display.println("AP");
1119. | else
1120. | display.println("STA");
1121. | break;
1122.
1123. | case 1:
1124. | display.setTextColor(WHITE);
1125. | display.println(F("Left for reset"));
1126. | display.setTextColor(BLACK,WHITE);
1127. | display.print("Operation mode: ");
1128. | changeSubmenuBoolean(networkType);
1129. | if(networkType)
1130. | display.println("AP");
1131. | else
1132. | display.println("STA");
1133. | display.setTextColor(WHITE);
1134. | break;
1135.
1136. | }
1137. | display.print(F("Network Name: "));
1138. | display.println(ssid);

1139. | display.print(F("Password: "));
1140. | display.println(password);
1141. | display.print(F("Ip address: "));
1142. | display.println(ipAddress);
1143. | display.display();
1144. | break;
1145. | }
1146.
1147. }
1148.
1149.
1150. }
1151. void setup() // runs on startup
1152. {
1153. | // Setup resz, runs once at startup:
1154. | Serial.begin(9600); //Serial Communication to the tester
1155. | Serial1.begin(115200);
1156. | //call the functions created, which should be executed on the first run
1157. displayInitialize();
1158. | //give the, to the function of the spikes
1159. | pinMode(JOYSTICK_BUTTON, INPUT_PULLUP);
1160. | pinMode(FANPIN, OUTPUT);
1161. | pinMode(IRRIGATIONPIN, OUTPUT);
1162. | pinMode(SPRAYPIN, OUTPUT);
1163. | pinMode(HEATERPIN, OUTPUT);
1164. | pinMode(LIGHTPIN, OUTPUT);
1165.
1166. }
1167.
1168. void loop() {
1169.
1170. // put your main code here, to run repeatedly:
1171. readJoystickValues();
1172. if(enableSerial) //sends data serially only if it receives input serially, so no resources are wasted
1173. | serialMonitorPrint();
1174. | changeMenuNumber(isSubMenu,maxMenuCount);
1175. | mainMenuSystem();
1176. if(joystickButtonState== true)
1177. {
1178. | if(millis()-lastTimeChange> menuChangeInterval)
1179. | {
1180. | isSubMenu= !isSubMenu;
1181. | maxMenuCount= MAX_MENU_COUNT;
1182. | currentSubmenuNumber= 0;
1183. | lastTimeChange= millis(); 1184.
| }
1185.
1186. }
1187. | transmitDateOnEsp(constructDateString());
1188. | readSensor();
1189. | outRelays();
1190. display.clearDisplay();
1191. }
1192.

# Bibliography

https://hu.wikipedia.org/wiki/Arduino#Szoftver https://en.wikipedia.org/wiki/Integrated_development_environment https://web.archive.org/web/20120227114343/http://tldp.fsf.hu/HOWTO/Program-Library-HOWTO-hu/index.html https://docs.arduino.cc/hardware/mega-2560/ https://hu.wikipedia.org/wiki/I%C2%B2C https://web.archive.org/web/20130511150526/http://www.nxp.com/documents/user_ manual/UM10204.pdf https://en.wikipedia.org/wiki/Hayes_AT_command_set https://web.archive.org/web/20151028101531/http://www.zoomtel.com/documentatio n/dial_up/100498E.pdf https://docs.arduino.cc/language-reference/ https://docs.arduino.cc/hardware/mega-2560/ https://docs.arduino.cc/resources/datasheets/A000067-datasheet.pdf https://docs.arduino.cc/software/ide/#ide-v1 https://docs.arduino.cc/programming/ https://www.ti.com/lit/an/sbaa565/sbaa565.pdf?ts=1741392150506&ref_url=https%2

53A%252F%252Fwww.google.com%252F (https://www.ti.com/lit/an/sbaa565/sbaa565.pdf?ts=1741392150506)

https://docs.arduino.cc/micropython/micropython-course/course/serial/ https://docs.arduino.cc/libraries/ssd1306/ https://github.com/lexus2k/ssd1306 https://docs.arduino.cc/libraries/adafruit-gfx-library/ https://github.com/adafruit/Adafruit-GFX-Library https://github.com/bonezegei/Bonezegei_DHT11 https://docs.arduino.cc/libraries/dht11/ https://github.com/dhrubasaha08/DHT11 https://blog.embeddedexpert.io/?p=613 https://randomnerdtutorials.com/guide-for-oled-display-with-arduino/ https://components101.com/modules/joystick-module https://www.researchgate.net/figure/The-pin-diagram-of-DHT11-temperature-

sensors_fig2_359068957 (https://www.researchgate.net/figure/The-pin-diagram-of-DHT11-temperature-sensors_fig2_359068957)

### https://www.google.com/url?sa=i&url=https%3A%2F%2Flastminuteengineers.com% 2Fcapacitive-soil-moisture-sensor-arduino%2F&psig=AOvVaw3d6lzLw9fkb919Blm9CME5&ust=1744631596137000 &source=images&cd=vfe&opi=89978449&ved=0CBQQjRxqFwoTCIjpmrD51IwDF

QAAAAAdAAAAABAE (https://www.google.com/url?psig=AOvVaw3d6lzLw9fkb919Blm9CME5&cd=vfe&opi=89978449)

### https://www.espressif.com/sites/default/files/documentation/0a-

esp8266ex_datasheet_en.pdf (https://www.espressif.com/sites/default/files/documentation/0a-esp8266ex_datasheet_en.pdf)

https://dcc-ex.com/reference/hardware/wifi-boards/esp-01.html#gsc.tab=0 https://docs.arduino.cc/resources/datasheets/A000067-datasheet.pdf https://www.google.com/url?sa=i&url=https%3A%2F%2Fwww.analog.com%2Fen% 2Fresources%2Ftechnical-articles%2Fi2c-primer-what-is-i2c-part-1.html&psig=AOvVaw0BWqK9NhBzePunKXn-zUoF&ust=1744908285940000&source=images&cd=vfe&opi=89978449&ved=0CB

QQjRxqFwoTCPjLr4yA3YwDFQAAAAAdAAAAABA9 (https://www.google.com/url?psig=AOvVaw0BWqK9NhBzePunKXn-zUoF&cd=vfe&opi=89978449)

### https://www.google.com/url?sa=i&url=https%3A%2F%2Fwww.industrialshields.com %2Fblog%2Farduino-industrial-1%2Fi2c-bus-on-the-arduino-based-plc-for- industrial-automation-192&psig=AOvVaw0BWqK9NhBzePunKXn-zUoF&ust=1744908285940000&source=images&cd=vfe&opi=89978449&ved=0CB

QQjRxqFwoTCPjLr4yA3YwDFQAAAAAdAAAAABBU (https://www.google.com/url?psig=AOvVaw0BWqK9NhBzePunKXn-zUoF&cd=vfe&opi=89978449)

### https://hu.wikipedia.org/wiki/Verzi%C3%B3kezel%C3%A9s

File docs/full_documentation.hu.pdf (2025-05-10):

# Liceul Teoretic “Salamon Ernő” Gheorgheni

# Lucrare de atestat

# disciplina

# INFORMATICĂ

Profesor coordonator: | Elev:
Csíki Zoltán | Kedves Attila-János

# Gheorgheni

2025

# Okos melegház

# Vezérlő

# -IoT project/Automatizált rendszer-

## Tartalom

# Bevezetés

### A vizsgamunkámon gondolkodva több egymástól eltérő projekt ötlet is

### megfogalmazódott bennem. Abban viszont biztos voltam, hogy amit véghez szeretnék

### vinni az legyen hasznos és képviseljen valamilyen értéket. Olyas valamit szerettem

### volna készíteni, ami nem csak számomra érdekes, hanem bárki más számára is

alkalmazható.

### Az automatizáció már mondhatni régóta létező technológia, mégis úgy

### gondolom, hogy nem elérhető mindenki számára, és kevesen alkalmazzák

### kiváltképpen a mezőgazdasági szektort nézve észlelhető, hogy egy egyszerű

### automatizációt alkalmazva nagy produktivitási eredmények érhetőek el. De ha ilyen

### hasznos lehet az automatizáció, akkor feltevődik a kérdés, hogy miért nincs

### elterjedve. Szerintem ez a kérdés abból adódik, hogy nem ezen technológiák nem

### kifejezetten elérhetőek magánszemélyek számára, és csak a nagy tökével rendelkező

### mezőgazdasági cégek engedhetik meg maguknak az efféle fejlesztéseket. Nézeteim

### szerint erre megoldást a nyílt forráskódú (opensource) projekt nyújthatnak. Ily módon

### könnyebben eljuthat a technológia olyan felhasználókhoz, akiknek azelőtt nem volt rá

lehetőségük.

### Az IoT, rövidítés az angol „Internet of things” szókapcsolatból jön, és

### magyarul annyit tesz, hogy dolgok internete. Ez röviden a különböző elektronikai

### eszközöket jelenti, amelyek képesek felismerni, esetleg feldolgozni valamilyen

### lényegi információt, és egy másik hálózaton lévő eszközzel kommunikálni. Ebből jól

### következik, hogy miért fontos, hogy egy automatizált vezérlő ilyen, IoT csoportba

### tartozó legyen. Egy melegházvezérlő egyik legfőbb tulajdonsága az, hogy a

### felhasználó távollétében is ellenőrizni tudja az aktuális paramétereket, ezt egy IoT

eszköz tudja.

Ezen rendszer legfőbb értéke az a szenzoros értékek feldolgozásában rejlik.

### Úgy terveztem, hogy képes legyen minden, egy melegházat jellemző paraméter

vizsgálatára. Ez a páratartalom, hőmérséklet, föld nedvessége, és a fény erősségé,

### kevésbé fontosnak tartottam, de meghagytam a széndioxid szint mérését, mint

### bővíthető funkció. Fontosnak tartottam a külső hőmérséklet és páratartalom

### vizsgálatát, hogy követhető legyen, hogy a környezeti tényezők hogyan befolyásolják

a melegház belső állapotát.

### Az internetes kezelés mellett fontos, hogy a funkciók helyszínen láthatóak és

### módosíthatóak legyenek. A nyomon követést egy 0.96 colos oled kijelző teszi

### lehetővé, ami menüpontokra leosztva jeleníti meg az adatokat. A módosításokat egy

joystick modul teszi lehetővé.

### Persze az adatok feldolgozása és kezelése mellett alapvető a belső környezet

aktív, mesterséges befolyásolása. Erre egy 6 csatornás relé modul nyújt lehetőséget,

amely be és ki kapcsolja a fény ellátást, párásítást, öntözést, és ventilátorok állapotát.

### Végső soron úgy gondolom, hogy fontos olyan automatizációs rendszerek

### létrehozása, amely elérhető széleskörű felhasználásra magán személyek, illetve

### kisvállalkozások számára egyaránt. Illetve szintén fontos, hogy egy ilyen

### automatizációs rendszer opensource legyen, hogy mindenki számára érthető és a

### jövőben továbbfejleszthető legyen. Innen fogva fel is eleveníteném Linus Torvalds

### egyik gondolatát: „Az intelligencia abból fakad, hogy az emberek képesek mások

### ötleteit felhasználni és továbbfejleszteni.”

# Fejlesztési lehetöségek

### A jelenlegi melegházvezérlő rendszer számos tekintetben sikeresen valósítja

### meg az alapvető funkciókat – például a hőmérséklet- és páratartalom-mérést, illetve

### azok OLED kijelzőn való megjelenítését, valamint a szenzoradatok továbbítását az

### ESP8266 modul segítségével egy belső hálózati szerverre. Ugyanakkor több irányban

### is lehetőség nyílik a rendszer továbbfejlesztésére és optimalizálására, amelyek

### nemcsak a teljesítményt növelik, hanem a rendszer megbízhatóságát és

funkcionalitását is jelentősen javítják.

### 1. Memóriaoptimalizálás

### A rendszer jelenlegi állapotában több helyen is redundáns, ismétlődő

### szövegkiírásokkal operál, például az OLED kijelzőre történő kiírásoknál. Ezeket a

### szövegrészeket célszerű statikus karaktertömbökbe, illetve #define vagy const char*

### változókba szervezni, így csökkenthető a SRAM terhelése. Emellett a String típus

### használata helyett ajánlott a C-szerű char[] tömböket alkalmazni, mivel a String típus

fragmentálhatja a memóriát hosszú futás során.

### 2. AT parancsok elhagyása

### Az ESP8266 vezérlése jelenleg valószínűleg AT parancsokon keresztül

### történik, ami nem a leghatékonyabb megoldás. Az AT firmware helyett ajánlott a

### NodeMCU (Lua) vagy az ESP8266 Arduino core használata, és a mikrokontroller

### közvetlen programozása. Így nem kell AT parancsokat küldeni soros kapcsolaton

### keresztül, hanem maga az ESP8266 veszi át a vezérlést, és az Arduino Mega csak

### szenzoradatokat továbbít. Ez növeli a válaszidőt, csökkenti a hibalehetőségeket, és

bővíti a lehetőségeket (pl. HTTPS kapcsolat, JSON kezelés).

### 3. Külső hálózatról való elérhetőség

### A rendszer jelenleg csak a belső hálózaton elérhető. Egy következő fejlesztési

### lépés lehet a webes interfész interneten keresztüli elérhetősége. Ez megvalósítható

### dinamikus DNS (DDNS) használatával, port forward segítségével a routerben, vagy –

### biztonságosabb és skálázhatóbb megoldásként – egy felhőalapú szerverre történő

### adatküldéssel (pl. MQTT, HTTPS POST REST API használatával). Az adatokat akár

egy valós idejű webes dashboard is megjelenítheti, pl. Node-RED.

### 4. Adatbiztonság és titkosítás

A továbbított adatok jelenleg valószínűleg titkosítatlanul utaznak a hálózaton,

### így egy fontos fejlesztési lehetőség a titkosított adatkommunikáció bevezetése. Ez

### történhet HTTPS használatával, vagy alacsonyabb szinten AES titkosítással (akár

### Arduino oldalon titkosítás, szerver oldalon dekódolás). Ez különösen fontos, ha az

eszköz internetre van kötve, vagy szenzitív adatokat is kezelne a jövőben.

### 5. Modularizált és újrahasznosítható kód

### A projekt további strukturálásával egy általánosabb, könnyen újrahasználható

### kódbázis is kialakítható. Célszerű az egyes hardverelemek kezelését külön

### osztályokba vagy függvénycsoportokba szervezni (pl. SHT szenzor kezelő, kijelző

### vezérlő, hálózati kommunikációs modul). Ez nemcsak olvashatóbbá és

### karbantarthatóbbá teszi a kódot, hanem előkészíti a projektet egy későbbi, több

modulból álló rendszerré való bővítésre (pl. több zónás melegház).

### 6. Hibatűrés és diagnosztika

### Hasznos lenne egy alapvető hibatűrő rendszer kialakítása, például watchdog

### timer használatával, amely újraindítja a rendszert, ha lefagy, vagy ha nem érkezik adat

### meghatározott ideig. Emellett egy logolási lehetőség is hasznos, amely menti a

hibákat vagy a főbb eseményeket egy SD kártyára vagy a felhőbe.

# Fejlesztési környezet

# Arduino IDE 2.0

### Egy arduino programozásában, mint a legtöbb programozási nyelv esetében

### egy úgynevezett Integrált fejlesztői környezet, röviden IDE használatos. Az

### integrált fejlesztői környezet (integrated development environment, IDE) egy olyan

### szoftveralkalmazás, amely átfogó létesítményeket biztosít a számítógépes

### programozók számára a szoftverfejlesztéshez. Az IDE általában legalább egy

forráskódszerkesztőből, automatizálási eszközökből és hibakeresőből áll.

### Az arduino programozására több IDE közül lehet választani. Az Arduino

### hivatalosan két különböző Arduino IDE-t kínál a fejlesztők számára:

### 1. Arduino IDE 1.x – Ez a klasszikus verzió, amely hosszú ideig az alapértelmezett

fejlesztői környezet volt. Egyszerű, gyors, és széles körben támogatott.
2. Arduino IDE 2.x – Az új generációs Arduino IDE, amely modern felhasználói felületet,

### fejlettebb szerkesztési funkciókat (pl. automatikus kódkiegészítés, sötét mód) és jobb

hibakeresési lehetőségeket kínál.

### Én a fejlesztés során az Arduino IDE 2.0 választottam, mivel ez a verzió

fejlesztőbarátabb környezetet nyújt.

### Ez az IDE könnyű hibakeresési lehetőségeket biztosit. Elérhető egy

úgynevezett soros monitor, ami segítségével nyomon követhetjük a változókat,

### lefutási időt, és függvények helyes meghívását. Ezt a kódba behelyezett egyszerű

### Serial.print(Val, Format) sorral tehetjük meg. Val – Az az adat, amit ki szeretnénk

### írni. Lehet szám, szöveg (string), karakter vagy változó. Format– Ez egy opcionális

paraméter, amely megadja, hogy milyen formátumban jelenjen meg az érték.

## Az arduino IDE 2 áttekintése

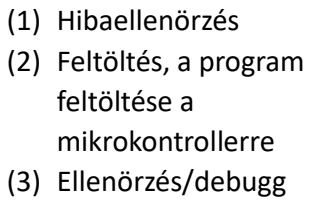
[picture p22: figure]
(1) Hibaellenörzés (2) Feltöltés, a program feltöltése a mikrokontrollerre (3) Ellenörzés/debugg

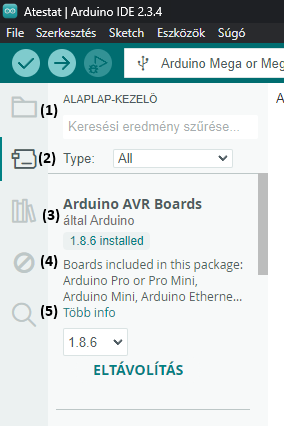
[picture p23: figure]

# Verziokezelő

Verziókezelés alatt több verzióval rendelkező adatok kezelését értjük.

### Leggyakrabban a mérnöki tudományokban és a szoftverfejlesztésben használnak

### verziókezelő rendszereket fejlesztés alatt álló dokumentumok, tervek, forráskódok és

### egyéb olyan adatok verzióinak kezelésére, amelyeken több ember dolgozik

### egyidejűleg. Az egyes változtatásokat verziószámokkal vagy verzióbetűkkel követik

nyomon.

### A verziókezelő rendszerek (angolul: Version Control Systems, röviden VCS)

### olyan szoftvereszközök, amelyek lehetővé teszik a programkód vagy más digitális

### fájlok változásainak nyomon követését az időben. A szoftverfejlesztés során a

### forráskód folyamatosan változik: új funkciók kerülnek beépítésre, hibák kerülnek

### javításra, vagy éppen kísérleti módosításokat végeznek a fejlesztők. Egy jól működő

verziókezelő rendszer lehetővé teszi ezen változások dokumentálását,

### visszakereshetőségét, valamint azt, hogy több fejlesztő egyszerre dolgozzon

ugyanazon a projekten anélkül, hogy egymás munkáját véletlenül felülírnák.

### A verziókezelés segítségével minden változtatás naplózásra kerül: ki, mikor és

### mit módosított. Ez nemcsak átláthatóbbá és biztonságosabbá teszi a fejlesztést, hanem

### visszaállíthatóvá is teszi egy korábbi, stabil állapotot, ha például egy új módosítás

### hibás működést okoz. A verziókezelés nemcsak a csapatmunkát segíti, hanem az

egyéni fejlesztő munkáját is rendszerezi és archiválja.

### (1.) A használatban lévő fájlok kezelése (2.) Alaplap-kezelő, különböző alaplapok telepítése (3.) Könyvtárkezelő, könyvtárak telepítése (4.) Hibakeresés, debugger (5.) Keresés kulcsszó alapján a projektben

### A legismertebb és legelterjedtebb verziókezelő rendszer ma a Git, amelyet

### Linus Torvalds – a Linux operációs rendszer megalkotója – fejlesztett ki. A Git

### elosztott verziókezelő, tehát minden fejlesztő saját gépén is rendelkezik a teljes

### projekt történetével. Ez különösen hasznos lehetőség, ha ideiglenesen nincs

### internetkapcsolat, vagy ha biztonsági mentésre van szükség. A Git rendszer

### legnépszerűbb online tárhelye a GitHub, amely nemcsak a verziókezelést teszi

### lehetővé, hanem egy teljes közösségi felületet is kínál, ahol más fejlesztők projektjei

is elérhetők, és akár együtt is lehet dolgozni.

# Könyvtárak

### A fejlesztés során a hatékony és gyors

programozás érdekében különféle könyvtárakat (angolul libraries) használunk.

### A "programkönyvtár" kifejezés egyszerűen egy olyan fájlt jelöl, ami lefordított

### tárgykódot (és adatot) tartalmaz, amit később egy programmal össze lehet

### szerkeszteni (link). A programkönyvtárak lehetővé teszik, hogy az alkalmazás

### modulárisabb, gyorsabban újrafordítható és könnyebben frissíthető legyen. A

programkönyvtárakat három típusba sorolhatjuk: statikus programkönyvtárak,

megosztott programkönyvtárak és dinamikusan betölthető (DL) programkönyvtárak.

### Az Arduino ökoszisztémában a könyvtárakat beépített kezelőfelületen

keresztül lehet telepíteni, és egyetlen #include utasítással beilleszthetők a kódba.

### Minden könyvtár egy adott hardver vagy funkció támogatására szolgál, például:

### #include <SPI.h> – A Serial Peripheral Interface (SPI) kommunikáció kezelésére

szolgál.

- #include <Wire.h> – Az I2C (Inter-Integrated Circuit) kommunikációt kezeli.

### - #include <Adafruit_GFX.h> – Az Adafruit Graphics Library, amely grafikus

objektumokat (szöveg, vonalak, formák) rajzol a kijelzőre.

### - #include <dht.h> – Egy egyszerű könyvtár a DHT11/DHT22 hőmérséklet- és

páratartalom-érzékelők kezelésére.

# Eszközök

### A projekthez különböző hardveres eszközöket alkalmaztam, melyek

### biztosítják a vezérlés, az adatgyűjtés és a kijelzés működését. Ezek az eszközök

egymással együttműködve valósítják meg a rendszer funkcionalitását.

## Mikrovezérlő: Arduino és ESP8266

### A projekt alapját egy Arduino Mega adja, amely a szenzorok és kijelzők

### kezeléséért felelős. Emellett az ESP8266 Wi-Fi modul lehetővé teszi a rendszer

számára, hogy hálózatra kapcsolódjon és adatokat küldjön egy szerverre.

## Arduino Mega

### Az Arduino mikrokontroller végzi az érzékelők adatainak feldolgozását és a

kimeneti eszközök vezérlését.

Az Arduino Mega 2560 egy ATmega2560-as mikrokontroller lapka.

### Rendelkezik 54 digitális be- és kimeneti tűvel (ebből 15 PWM-kimenetként

### használható), 16 analóg bemenettel, 4 UART (hardveres soros port), 16 MHz-es

### kristályoszcillátorral, USB-csatlakozóval, tápcsatlakozóval, ICSP-fejléccel és reset-

gombbal.

### Az arduino mega felépítése

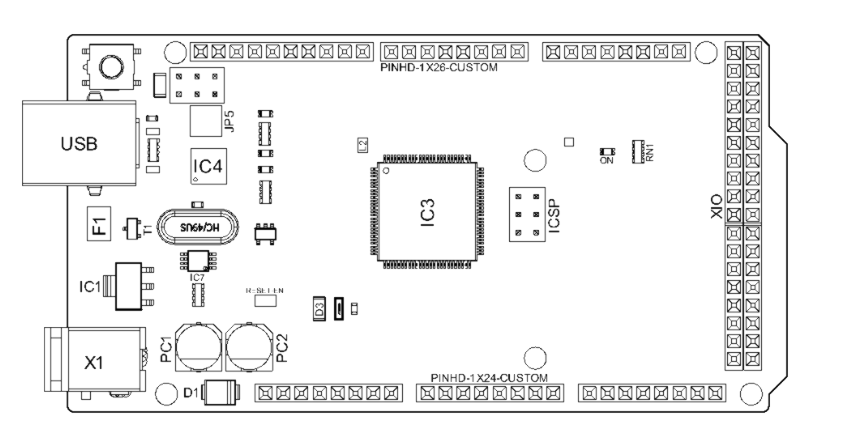
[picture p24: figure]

### Az arduino mega lábkiosztása


## ESP8266:

### Egy önálló Wi-Fi modulként is működő mikrokontroller, amely AT parancsok

### segítségével kommunikál soros kapcsolaton keresztül az Arduinóval, és lehetővé teszi

az adatok internetre való továbbítását.

### Az ESP8266 egy rendkívül népszerű, alacsony költségű Wi-Fi képes mikrokontroller

### modul, amelyet az Espressif Systems fejlesztett ki. A modul integrált TCP/IP

### protokoll stackkel és 32 bites RISC CPU-val rendelkezik, amely akár 80–160 MHz

### órajellel is működhet. Beépített Wi-Fi funkciójának köszönhetően ideális választás

### IoT (Internet of Things) projektekhez, mivel képes önállóan csatlakozni vezeték

### nélküli hálózatokra, vagy akár egy másik mikrokontroller kiegészítőjeként működni

Wi-Fi modemként.

Az ESP-01 mindössze 8 lábbal rendelkezik, ebből kettő GPIO portként (GPIO0,

### GPIO2) használható, a többi a tápellátást, a soros kommunikációt (TX/RX), illetve a

vezérlést szolgálja.

### A programozása történhet AT parancsokkal egy másik mikrokontrolleren

### keresztül (például Arduino UNO-val), vagy közvetlenül is, ha rendelkezésre áll

megfelelő USB–soros átalakító és az Arduino IDE-ben a megfelelő firmware.

Az alábbi ábrán látható a mikrokontroller tüskéinek funkciója (Ábra 1), illetve egy példa a

csatlakoztatására egy arduino mega-val (Ábra 2.).


(Ábra 1.)


### (Ábra 2,)

## Érzékelők (szenzorok)

### A rendszer működéséhez különféle érzékelőket használtam, amelyek lehetővé

teszik a környezeti adatok mérését és feldolgozását.

### DHT11 – Hőmérséklet- és páratartalom-érzékelő

- Lehetővé teszi a levegő hőmérsékletének és páratartalmának mérését.
- Digitális kimenetet biztosít, amelyet könnyen feldolgozhat az Arduino.


### (A szenzor tüskéinek kimenete)

### Talajnedvesség-érzékelő

### - A talaj nedvességtartalmát méri, amely segíthet az automatikus öntözés

szabályozásában.
- Analog kimenetet ad, amely az arduino egyik analog tüskéjével fogadható.

(Az érzékelő tüskéinek funkciója)

### Fényszint érzékelő LDR

- Fotoellenállás, az ellenállás mértéke a rásugárzó fény intenzitásától függ.
- Az elleállás az arduino egyik analog bemenetével olvasható.

## Kijelző: OLED SSD1306

### A 0.96 colos OLED kijelző (SSD1306) segítségével a mért adatok vizuálisan is megjeleníthetők, menüpontokra bontva . Az Adafruit SSD1306 és GFX könyvtárak használatával egyszerűen lehet szöveget és grafikus elemeket (például ikonokat vagy

diagramokat) kirajzolni.

### Az OLED (Organic Light Emitting Diode) technológiát használó SSD1306 típusú kijelző egy alacsony fogyasztású, nagy kontrasztú megjelenítő, amelyet gyakran használnak beágyazott rendszerekben, mint például Arduino vagy ESP8266

mikrokontrollerekkel. A kijelző leggyakoribb változata 0,96 hüvelyk átmérőjű,

### 128x64 pixeles felbontással rendelkezik, és egy SSD1306 jelű vezérlőchipet tartalmaz, amely az OLED mátrix működtetéséért felel. Ez a vezérlő támogatja az I2C és SPI kommunikációs protokollokat is, ami egyszerű csatlakoztatást és gyors

adatátvitelt tesz lehetővé.

### A kijelzők előnyei közé tartozik a nagy fényerejű, kiváló kontrasztú kép, mivel minden pixel önálló fényt bocsát ki, így nincs szükség háttérvilágításra. Kis méretük és alacsony energiaigényük miatt ideálisak mobil és IoT alkalmazásokhoz, például

szenzoradatok vagy egyszerű menük megjelenítésére.

A következő ábrákon látható az arduinoval való kommunikációhoz szükséges csatlakozások. Az első ábrán (Ábra 1) látható egy arduino uno-val létrehozott kapcsolat, I2C kommunikációs protokolt használva. A második ábrán (Ábra 2) a kijelző tüskéinek a funkciója látható (szintén I2C kommunikációs protokol hassználatával). A harmadik ábrán (Ábra 3) szintén a tüskék funkciója látható, viszont

egy SCA kommunikációt használó kijelzővel.


## Joystick modul

## - A projektben egy két tengelyes analóg joystick modult használok, amely lehetővé teszi a felhasználó számára, hogy fizikai bemenetet adjon a

rendszernek.

## - Ez a modul két potenciométerből és egy nyomógombból áll, így X-Y irányú

mozgás érzékelésére és kattintásra is képes.

## Az alábbi képeken láthatóak a modul csatlakozói, illetve, az elmozdulás

viszonyában visszatérített értékek .

Ábra 1.

Ábra 3. | Ábra 2.

# Protokolok

### A projektben különböző kommunikációs protokollokat használok az eszközök

közötti adatátvitel megvalósítására. Ezek a protokollok lehetővé teszik a szenzorok,

kijelzők és az ESP8266 Wi-Fi modul kommunikációját az Arduino-val.

## 1. I²C (Inter-Integrated Circuit) protokoll

- Az I²C egy soros kommunikációs protokoll, amelyet főként érzékelők,

### kijelzők és más perifériák csatlakoztatására használnak. Két vezetékes

rendszer, amely egy órajelvonalból (SCL) és egy adatvonalból (SDA) áll.

### - Az I²C jellemzően kis távolságú, viszonylag alacsony sebességű IC és fedélzeti rendszerek közötti kommunikációra szokás alkalmazni

- Az I²C (Inter-Integrated Circuit) egy multi-master, multi-slave,

### csomagkapcsolt soros busz, melyet a Philips Semiconductor (ma NXP

Semiconductors) fejlesztett ki.

### - Ebben a projektben az I2C protokoll a kijelzővel való kommunikációra van használva, de mint fejlesztési lehetőség bővíthető egy RTC modullal, az idő

valós idejű nyomon követesére.

### Az I2C protokoll ábrákon való bemutatása


## 2. UART (Universal Asynchronous Receiver-Transmitter) – Soros

### kommunikáció - Az univerzális aszinkron adóvevő (röviden UART) egy olyan hardver, amely

fordítást végez a soros és párhuzamos interfészek között.

### - Az UART protokoll az egyik leggyakrabban használt kommunikációs módszer mikrokontrollerek és külső modulok között. Két vezetékes rendszeren alapul: TX-Transmitter – Adó, RX-Receiver – Vevő - A projektemben az arduino és az esp8266 van sorosan összekapcsolva

### Az UART protokoll ábrán


### 3. AT protokol

### - A protokoll segítségével egy mikrokontroller vagy számítógép soros (UART) kommunikáción keresztül adhat utasításokat egy eszköznek, például egy

ESP8266 Wi-Fi modulnak.

### - Az AT-parancsok (vagy Hayes AT-parancsok) egy szabványos modemvezérlő parancskészlet, amelyet eredetileg a Hayes Microcomputer Products fejlesztett ki az 1980-as években. Az "AT" rövidítés az "attention" (figyelem) szóból származik, mivel minden parancs az "AT" előtaggal kezdődik, jelezve a

modem számára, hogy egy új utasítás következik.

### - Példák az at parancsok használatára esp-vel: - AT+CWJAP="SSID","PASSWORD" – Wi-Fi hálózatra csatlakozás

(ESP8266).
- AT+CIFSR-Ip cim lekérdezése.

### - AT+CIPSTART="TCP","192.168.1.50",8080-szerverhez való

csatlakozás.

# Használt programozási környezet

A projekt megvalósításához az Arduino programozási nyelvet alkalmaztam,

amely a C és C++ nyelveken alapul, de leegyszerűsített szintaxissal rendelkezik.

### A programozás során az Arduino natív függvényeire támaszkodtam, például:

### 1. pinMode(pin, mode) Egy adott digitális láb bemenetként (INPUT), kimenetként (OUTPUT), vagy

bemenetként belső felhúzó ellenállással (INPUT_PULLUP) történő beállítása.

### Konkrét példa: - pinMode(13, OUTPUT); // D13 láb kimenetként beállítása (pl. LED vezérléséhez) - pinMode(2, INPUT); // D2 láb bemenetként beállítása (pl. gombhoz) - pinMode(3, INPUT_PULLUP); // D3 bemenet, belső felhúzó ellenállással 2. digitalWrite(pin, value)

Egy digitális kimenetre (HIGH vagy LOW) jelet küld.

### Konkrét példa: - digitalWrite(13, HIGH); // Bekapcsolja a D13-ra kötött LED-et - digitalWrite(13, LOW); // Kikapcsolja a D13-ra kötött LED-et 3. digitalRead(pin)

Egy digitális bemenet állapotát (HIGH vagy LOW) olvassa be.

### 4. analogWrite(pin, value) Egy PWM (Pulse Width Modulation) jelet generál a megadott kimeneten. Az

érték 0 és 255 között lehet. Csak PWM-képes lábakon működik.

### Konkrét példa: analogWrite(9, 128); // A D9 lábon 50%-os kitöltési tényezőjű PWM jel 5. analogRead(pin)

Egy analóg bemenet értékét olvassa be 0 és 1023 között.

### Konkrét példa: int Hömérséklet = analogRead(A0); // Az A0 láb feszültségét olvassa be (0-1023) 6. delay(ms)

Egy megadott ezredmásodpercig (ms) megállítja a program futását.

### Konkrét példa: delay(1000); // 1 másodperces késleltetés 7. millis()

A program indítása óta eltelt időt adja vissza ezredmásodpercben. Konkrét példa: unsigned long inditasotaElteltIdo = millis();

### 8. map(value, fromLow, fromHigh, toLow, toHigh)

Egy számot egyik tartományból a másikba skáláz át.
Konkrét példa: int szenzor = analogRead(A0);
int skálázva = map(szenzor, 0, 1023, 0, 255);

# Rendszerterv és kapcsolási rajzok

# Áttekintés

### A rendszer célja a melegház környezeti paramétereinek monitorozása és

### vezérlése.Az arduino mega fogadja az adatokat a szenzoroktól, a megadott

### paraméterek alapján vezérli a rellé-modult. Az arduino az esp8266 wifi modulal

### kommunikálva elküldi az adatokat. Az arduino I2C kommunikációval vezérli az oled

### kijelzöt. A joystick modul megadja felhasználó által bevitt vezérlést, két analóg

bemeneten keresztül és egy digitális, gombon keresztül.

# Kapcsolási Rajz


# Áramkör


# Kötözési táblázat

Arduino Mega 2560 Pin | Csatlakoztatott Eszköz | Kapcsolat típusa | Megjegyzés
3V ESP8266 | | Tápellátás | Feszültség
5V | Több modul (pl. OLED, DHT) | Tápellátás | Feszültség
GND | Több modul (az összes) | Földelés | Közös GND
D2 | Nyomógomb | Digitális bemenet | Gomb
D3 | DHT11 | Digitális bemenet | Hőmérséklet/páratartalom
D4 | DHT11 | Digitális bemenet | Hőmérséklet/páratartalom
D5-D10 | Relé modul | Digitális kimenet | Relé vezérlés
Serial1 RX | ESP8266 TX | Soros kommunikáció | ESP TX – Mega RX
Serial1 TX | ESP8266 RX | Soros kommunikáció | ESP RX – Mega TX
A1 | Joystick modul X-tengely | Analóg bemenet | X mozgás
A2 | Joystick modul Y-tengely | Analóg bemenet | Y mozgás
A3 | Fény szenzor | Analóg bemenet | Fényérékeny ellenállás
A6 | C02 szenzor | Analóg bemenet | Széndioxid szint
SDA (A4) | OLED kijelző, I2C modul | I2C kommunikáció | Adatvonal
SCL (A5) | OLED kijelző, I2C modul | I2C kommunikáció | Óravonal

# A kész vezérlő


# Forráskód

1. //A használt könyvtárak beillesztése
2. #include <SPI.h>
3. #include <Wire.h>
4. #include <Adafruit_GFX.h>
5. #include <Adafruit_SSD1306.h>
6. #include <dht.h>
7. #include <SoftwareSerial.h>
8. #include <Vector.h>
9. #include <avr/wdt.h>
10.
11. //Az eszközök csatlakoztatott tüskéi és az állandó értékek megadása, illetve a használandó objektumok deklarálása
12. //Temp and humidity
13. #define dht1 3
14. #define dht2 4
15. // A két DHT szenzor objektumok deklarálása
16. dht DHT1;
17. dht DHT2;
18. //Moisture sensor
19. #define MOISTURESENSOR A0
20. #define MINMOISTURE 500
21. #define MAXMOISTURE 180
22. //Output relays
23. #define FANPIN 7
24. #define IRRIGATIONPIN 8
25. #define SPRAYPIN 9
26. #define HEATERPIN 10
27. #define LIGHTPIN 6
28. // Az oled kijelző deklarálása i2c kommunikációval
29. #define SCREEN_WIDTH 128
30. #define SCREEN_HEIGHT 64
31. #define OLED_RESET -1
32. #define SSD1306_I2C_ADDRESS 0x3C
33. Adafruit_SSD1306 display(SCREEN_WIDTH, SCREEN_HEIGHT, &Wire, OLED_RESET); 34.
35. //Joystick
36. #define JOYSTICK_X A1
37. #define JOYSTICK_Y A2
38. #define JOYSTICK_BUTTON 2
39. #define JOYSTICK_MAXTRESHOLD 900
40. #define JOYSTICK_MINTRESHOLD 100
41.
42. #define MAX_MENU_COUNT 7 // a menupontok 0-tol vannak indexelve, igy ez a szam 1-el kissebb
43. #define MIN_CHANGE_SPEED 0
44. #define MAX_CHANGE_SPEED 100
45. #define SERIALPRINTINTERVALL 5000
46. #define DEBUG 0
47. #define NETWORKTYPE 0 //0-STA, 1 AP
48. #define SERIALNUMBER 123456
49. #define WIFINAME "DIGI_57c120"
50. #define PASSWORD "195da83e"
51. #define AITHINKER "AI-THINKER_394EDC"
52. // Bemeneti és kimeneti változók deklarálása:
53. // Bemeneti változók (érzékelők adatai):
54. byte insideTemperature, outsideTemperature, insideHumidity, outsideHumidity, soilMoistureLevel, lightIntensity;
55. // Kimeneti változók (vezérelt eszközök):
56. enum DeviceState
57. {
58. | OFF, | // 0
59. | ON, | // 1
60. | AUTO | // 2

61. };
62. DeviceState fanState, irrigationState, sprayState, heaterState, lightState; 63.
64. //Belső változók deklarálása:
65. //wifi
66. | String ssid = String(WIFINAME); | // A wifi neve AI-THINKER_394EDC
67. | String password = String(PASSWORD); | // A wifi hálózat jelszava
68. String ipAddress = "";
69. int joystickAxisX, joystickAxisY; //A beviteli eszkoz (joystick) tengelyekre vonatkozo valtozoi
70. bool joystickButtonState;
71. byte currentMenuNumber;
72. byte currentSubmenuNumber;
73. byte maxMenuCount;
74. bool isSubMenu;
75. long long lastTimeMenuRefresh;
76. // Button lenyomas kozotti eltelt ido vizsgalata
77. const byte menuChangeIntervall = 500; // menu/submenu valtozas
78. long long lastTimeChange = 0;// Left/Right valtozas kozott eltelt ido vizsgalata
79. long long lastTimeSerial = 0;
80. const char deviceStateStrings[3][4] = {"OFF", "ON","AUTO"}; // kiirashoz a konnyebben erthetosegert kiirando szoveg
81. //Min és max célváltozók deklarálása:
82. byte maxTemp, minTemp, maxHumidity, minHumidity, maxMoisture, minMoisture, minLightLevel;
83. const char* languages[3] = {"Eng","Hun","Ro"};
84. byte languageSet;
85. bool enableSerial = DEBUG;
86. bool networkType = NETWORKTYPE;
87. byte changeSpeed = 20;
88. byte connectionId;
89. //A fömenü értékeinek flash memóriában való tárolása
90. const char menu1[] PROGMEM = "Device Owerview";
91. const char menu2[] PROGMEM = "Sensor Overview";
92. const char menu3[] PROGMEM = "Temperature Controll";
93. const char menu4[] PROGMEM = "Humidity Controll";
94. const char menu5[] PROGMEM = "Irrigation Controll";
95. const char menu6[] PROGMEM = "Light Controll";
96. const char menu7[] PROGMEM = "System Settings";
97. const char menu8[] PROGMEM = "Network Settings";
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

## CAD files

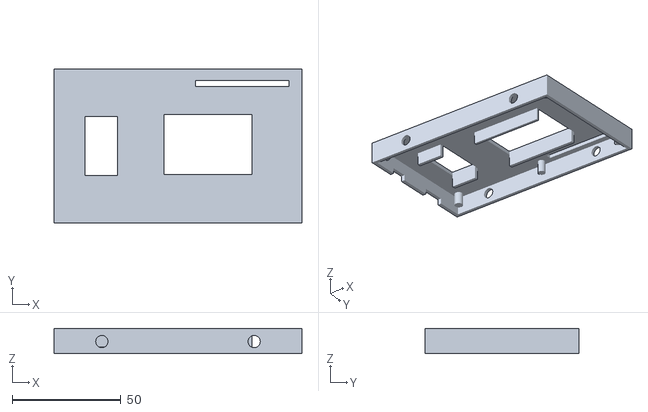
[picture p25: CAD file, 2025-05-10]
hardware/3d_case/GreenhouseController v2.stl
114.0 x 71.0 x 11.5

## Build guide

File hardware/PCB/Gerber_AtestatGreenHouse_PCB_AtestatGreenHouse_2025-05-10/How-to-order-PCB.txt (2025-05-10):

How to Order PCB

Please refer to:
https://docs.easyeda.com/en/PCB/Order-PCB

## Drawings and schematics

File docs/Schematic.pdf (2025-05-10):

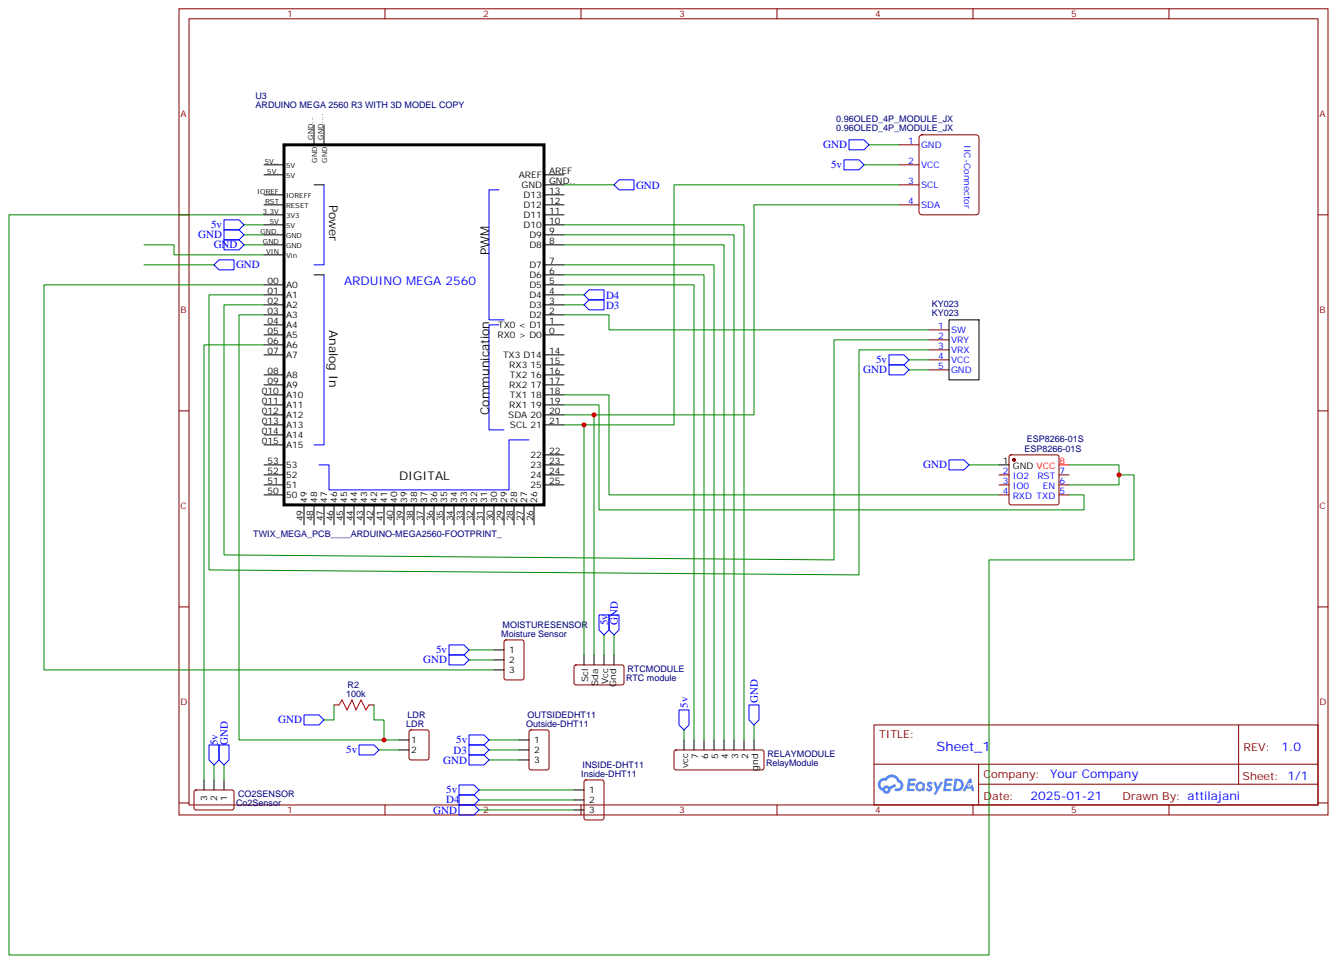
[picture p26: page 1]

ARDUINO MEGA 2560 R3 WITH 3D MODEL COPY

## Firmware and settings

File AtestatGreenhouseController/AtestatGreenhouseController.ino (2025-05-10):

//A használt könyvtárak beillesztése
#include <SPI.h>
#include <Wire.h>
#include <Adafruit_GFX.h>
#include <Adafruit_SSD1306.h>
#include <dht.h>
#include <SoftwareSerial.h>
#include <Vector.h>
#include <avr/wdt.h>

//Az eszközök csatlakoztatott tüskéi és az állandó értékek megadása, illetve a használandó objektumok deklarálása
//Temp and humidity
#define dht1 3
#define dht2 4
// A két DHT szenzor objektumok deklarálása
dht DHT1;
dht DHT2;
//Moisture sensor
#define MOISTURESENSOR A0
#define MINMOISTURE 500
#define MAXMOISTURE 180
//Output relays
#define FANPIN 7
#define IRRIGATIONPIN 8
#define SPRAYPIN 9
#define HEATERPIN 10
#define LIGHTPIN 6
// Az oled kijelző deklarálása i2c kommunikációval
#define SCREEN_WIDTH 128 
#define SCREEN_HEIGHT 64
#define OLED_RESET     -1 
#define SSD1306_I2C_ADDRESS 0x3C
Adafruit_SSD1306 display(SCREEN_WIDTH, SCREEN_HEIGHT, &Wire, OLED_RESET);

//Joystick
#define JOYSTICK_X A1
#define JOYSTICK_Y A2
#define JOYSTICK_BUTTON 2
#define JOYSTICK_MAXTRESHOLD 900
#define JOYSTICK_MINTRESHOLD 100

#define MAX_MENU_COUNT 7 // a menupontok 0-tol vannak indexelve, igy ez a szam 1-el kissebb
#define MIN_CHANGE_SPEED 0
#define MAX_CHANGE_SPEED 100
#define SERIALPRINTINTERVALL 5000
#define DEBUG 0
#define NETWORKTYPE 0 //0-STA, 1 AP
#define SERIALNUMBER 123456
#define WIFINAME "DIGI_57c120"
#define PASSWORD "195da83e"
#define AITHINKER "AI-THINKER_394EDC"
// Bemeneti és kimeneti változók deklarálása:
  // Bemeneti változók (érzékelők adatai):
    byte insideTemperature, outsideTemperature, insideHumidity, outsideHumidity, soilMoistureLevel, lightIntensity; 
  // Kimeneti változók (vezérelt eszközök):
    enum DeviceState 
    {
      OFF,   // 0
      ON,    // 1
      AUTO   // 2
    };
    DeviceState fanState, irrigationState, sprayState, heaterState, lightState;

//Belső változók deklarálása:
  //wifi
  String ssid = String(WIFINAME);    // A wifi neve AI-THINKER_394EDC
  String password = String(PASSWORD);    // A wifi hálózat jelszava
  String ipAddress = ""; 
  int joystickAxisX, joystickAxisY; //A beviteli eszkoz (joystick) tengelyekre vonatkozo valtozoi 
  bool joystickButtonState;
  byte currentMenuNumber;
  byte currentSubmenuNumber;
  byte maxMenuCount;
  bool isSubMenu;
  long long lastTimeMenuRefresh;
  // Button lenyomas kozotti eltelt ido vizsgalata
  const byte menuChangeIntervall = 500; // menu/submenu valtozas
  long long lastTimeChange = 0;// Left/Right valtozas kozott eltelt ido vizsgalata
  long long lastTimeSerial = 0;
  const char deviceStateStrings[3][4] = {"OFF", "ON","AUTO"}; // kiirashoz a konnyebben erthetosegert kiirando szoveg
  //Min és max célváltozók deklarálása:
  byte maxTemp, minTemp, maxHumidity, minHumidity, maxMoisture, minMoisture, minLightLevel;
  const char* languages[3] = {"Eng","Hun","Ro"};
  byte languageSet; 
  bool enableSerial = DEBUG;
  bool networkType = NETWORKTYPE;
  byte changeSpeed = 20;
  byte connectionId;
//A fömenü értékeinek flash memóriában való tárolása
  const char menu1[] PROGMEM = "Device Owerview";
  const char menu2[] PROGMEM = "Sensor Overview";
  const char menu3[] PROGMEM = "Temperature Controll";
  const char menu4[] PROGMEM = "Humidity Controll";
  const char menu5[] PROGMEM = "Irrigation Controll";
  const char menu6[] PROGMEM = "Light Controll";
  const char menu7[] PROGMEM = "System Settings";
  const char menu8[] PROGMEM = "Network Settings";
  const char* const messages[] PROGMEM = {menu1,menu2,menu3,menu4,menu5,menu6,menu7,menu8};

void readSensor()//A szenzorok által mért értékek olvasása
{
  int insideSensor = DHT1.read11(dht1); 
  insideTemperature = DHT1.temperature;
  insideHumidity = DHT1.humidity;
  int outsideSensor = DHT2.read11(dht2);
  outsideTemperature = DHT2.temperature;
  outsideHumidity = DHT2.humidity;
  soilMoistureLevel = map(analogRead(MOISTURESENSOR), MINMOISTURE, MAXMOISTURE, 0, 100);
}
//Fuggvények
void restartArduino() // az arduino ujraindíndítása
{
  wdt_enable(WDTO_15MS); // Watchdog aktiválása 15ms időre
  while (1);             // Várakozás az újraindításra/Lefagyasztjuk a programot
}
void espSetup() // az esp inicializálása
{    
  sendData("AT+RST\r\n",2000,enableSerial); // reset module
  if(networkType)
  {
    ssid = String(AITHINKER);
    password = "-";
    sendData("AT+CWMODE=2\r\n",1000,enableSerial); // configure as access point
  }
  else
  {
    ssid = String(WIFINAME);
    password = String(PASSWORD);
  delay(1000); // kis extra várakozás
  //configure as station mode, connect to wifi
  sendData("AT+CWMODE=1\r\n", 1000, enableSerial);
  // Connect to wifi (ssid+password)
  String connectCommand = "AT+CWJAP=\"" + ssid + "\",\"" + password + "\"\r\n";
  sendData(connectCommand, 8000, enableSerial);
  } 
  sendData("AT+CIPMUX=1\r\n",1000,enableSerial); // configure for multiple connections
  sendData("AT+CIPSERVER=1,80\r\n",1000,enableSerial); // turn on server on port 80
}
void getIp() // Az ip cím lekérdezése
{ 
  delay(1000);
  // IP cím lekérése
  ipAddress = sendData("AT+CIFSR\r\n", 1000, enableSerial);
  byte first = ipAddress.indexOf('"');
  byte second = ipAddress.indexOf('"', first + 1);
  if (first != -1 && second != -1) 
  {
  ipAddress = ipAddress.substring(first + 1, second);
  } else 
  {
    Serial.println("ip error");
  }
}
String booleanStateOnOff(bool state) // bool stringként való visszatérítése kiiratás céljából
{
  if(state)
    return "On";
  else
    return "Off";
}
String sendData(String command, const int timeout, boolean debug) //Parancsok küldése az esp-nek, és a válaszának fogadása
{
    String response = "";
    Serial1.print(command);
    long int time = millis();
    while( (time+timeout) > millis())
    {
      while(Serial1.available())
        {
            char c = Serial1.read(); // read the next character.
            response+=c;
        }  
    }
    if(debug)
          {
          Serial.print(response); //displays the esp response messages in arduino Serial monitor
          }
    return response;
}
void espsend(String date) //Szoveg parancsának felépitése és elkuldése
{
  String cipSend = " AT+CIPSEND=";
  cipSend += connectionId; 
  cipSend += ",";
  cipSend +=date.length();
  cipSend +="\r\n";
  sendData(cipSend,1000,enableSerial);
  sendData(date,1000,enableSerial); 
}
void showMessageOnScreen(String message) // Szöveg megjelenítése a kijelző közepén 
{
  display.clearDisplay();
  display.setTextSize(1);      // Szöveg méretének meghatározása
  display.setTextColor(WHITE);
  display.setCursor(0, 10);   // Szöveg pozíciójának megadása
  display.println(message);
  display.display();
}
void transmitDateOnEsp(String data)// Az esp-vel való kommunikáció kezelése
{
  if(Serial1.available())
  {
    if(Serial1.find("+IPD,")) //kérés érkezésének figyelése
    {
     showMessageOnScreen("Network communication\nin progress...");
     delay(300);
     connectionId = Serial1.read()-48;
      String webpage = data;
      webpage+=connectionId;
      espsend(webpage);
     }
     String closeCommand = "AT+CIPCLOSE=";  ////////////////close the socket connection////esp command 
     closeCommand+=connectionId; // append connection id
     closeCommand+="\r\n";
     sendData(closeCommand,3000,enableSerial);
  }
}
String constructDateString() //A hálózatra kiküldött string felépítése a vezérlő adatai alapján
{
  String dataString = "InTemp=" + String(insideTemperature) + "&OutTemp=" + String(outsideTemperature) + "&InHum=" + String(insideHumidity) + "&OutHum=" + String(outsideHumidity) + "&Moi=" + String(soilMoistureLevel) + "&Light=" + String(lightIntensity) + "&maxTemp=" + String(maxTemp) + "&minTemp=" + String(minTemp) + "&maxHum=" + String(maxHumidity) + "&minHum=" + String(minHumidity) + "&maxMoi=" + String(maxMoisture) ;
  dataString +="&minMoi=" + String(minMoisture) + "&minLightLevel=" + String(minLightLevel)+"&fanState=" + String(fanState) + "&irrigationState=" + String(irrigationState) + "&sprayState=" + String(sprayState) + "&heaterState=" + String(heaterState) + "&lightState=" + String(lightState);
  String html = "<!DOCTYPE html><html><head><meta http-equiv=\\\"refresh\\\" content=\\\"5\\\"><title>Greenhouse" + String(SERIALNUMBER) + "</title></head><body>" + dataString + "</body></html>";

  return html;
}
void outRelays() // A rellé modulok be- és kikapcsolása az állapotuk alapjánminLightLevel
{
  if(heaterState == 2)
  {
    if(insideTemperature < minTemp)
      digitalWrite(HEATERPIN, HIGH);
    if(insideTemperature >(minTemp+maxTemp)/2)
      digitalWrite(HEATERPIN, LOW);
  } 
    if (heaterState == 1) 
      digitalWrite(HEATERPIN, HIGH);
    if (heaterState == 0)
      digitalWrite(HEATERPIN, LOW);
  if(fanState == 2)
  {
    if(insideTemperature > maxTemp)
      digitalWrite(FANPIN, HIGH);
    if(insideTemperature < (minTemp+maxTemp)/2)
      digitalWrite(FANPIN, LOW);
  }
  if(fanState == 1)
      digitalWrite(FANPIN, HIGH);
  if(fanState == 0)
      digitalWrite(FANPIN, LOW);
  if(irrigationState == 2)
  {
    if(soilMoistureLevel < minMoisture)
      digitalWrite(IRRIGATIONPIN, HIGH);
    if(soilMoistureLevel > maxMoisture)
      digitalWrite(IRRIGATIONPIN, LOW);
  }
  if(irrigationState == 1)
      digitalWrite(IRRIGATIONPIN, HIGH);
  if(irrigationState == 0)
      digitalWrite(IRRIGATIONPIN, LOW);
  if(lightState == 2)
  {
    if(lightIntensity < minLightLevel)
      digitalWrite(LIGHTPIN, HIGH);
    if(lightIntensity>=minLightLevel)
      digitalWrite(LIGHTPIN,LOW);
  }
  if(lightState == 1)
      digitalWrite(LIGHTPIN, HIGH);
  if(lightState == 0)
      digitalWrite(LIGHTPIN, LOW);
  switch (sprayState)
  {
    case 0:digitalWrite(SPRAYPIN, LOW);break;
    case 1:digitalWrite(SPRAYPIN, HIGH);break;
    case 2:
    if(insideHumidity < minHumidity)
      digitalWrite(SPRAYPIN, HIGH);
    if(insideHumidity > (minHumidity+maxHumidity)/2)
      digitalWrite(SPRAYPIN, LOW);
      break;
  }
  
}
short languageChooser (short currentLanguage)// A nyelvválasztó vátltozó változtatása
{
    if (joystickAxisY > JOYSTICK_MAXTRESHOLD)
  {
    currentLanguage ++;
    if(currentLanguage > 2)
      currentLanguage = 0;
  }
  else
  {
    if (joystickAxisY < JOYSTICK_MINTRESHOLD)
    {
      currentLanguage --;
      if(currentLanguage < 0)
        currentLanguage = 2;

    }

  }
  delay(changeSpeed+100);
  return currentLanguage;
}
void changeSubmenuBoolean(bool &booleanToChange)// Bool menüváltozó megváltoztatása, joystickAxisY alapján 
{
  if (joystickAxisY > JOYSTICK_MAXTRESHOLD || joystickAxisY < JOYSTICK_MINTRESHOLD)
  {
    booleanToChange = !booleanToChange;
  }
  delay(changeSpeed+30);
}
short changeSubmenuVariable(short numberToChange) // A számértékek változtatása az almenükben
{

  if (joystickAxisY > JOYSTICK_MAXTRESHOLD)
  {
    numberToChange++;
  }
  else
  {
    if (joystickAxisY < JOYSTICK_MINTRESHOLD)
    {
      numberToChange--;
    }
  }
  delay(changeSpeed+30);
  return numberToChange;
  
}
DeviceState changeDeviceState(DeviceState deviceState)// Az eszközok állapotának változtatása
{
  short counter = deviceState;
  
  if (joystickAxisY > JOYSTICK_MAXTRESHOLD)
  {
    counter ++;
    if(counter > 2)
      counter = 0;
  }
  else
  {
    if (joystickAxisY < JOYSTICK_MINTRESHOLD)
    {
      counter --;
      if(counter < 0)
        counter = 2;
    }
    else return static_cast<DeviceState>(counter);
  }
  delay(changeSpeed+100);
  return static_cast<DeviceState>(counter);
}
void changeMenuNumber(bool isSubMenu, byte maxNumber)// A menü és az almenü értékének növelése/csökkentése
{
  if(millis()-lastTimeMenuRefresh > changeSpeed+50)//Módosítások közötti idő vizsgálata, a megfelő működésért
  {
      lastTimeMenuRefresh = millis();
    if(isSubMenu) // dontés, hogy a főmenü, vagy az almenü értékét kell-e változtatni
    {
      if (joystickAxisX > JOYSTICK_MAXTRESHOLD)
      {
        if(maxNumber > currentSubmenuNumber)
          currentSubmenuNumber++;
        else 
          currentSubmenuNumber = 0;
        
      }
    else
    {
      if (joystickAxisX < JOYSTICK_MINTRESHOLD)
      {
        if(currentSubmenuNumber > 0)
          currentSubmenuNumber--;
        else
        currentSubmenuNumber = maxNumber;
        
      }     
    }
    }
    else 
    {
        if (joystickAxisX > JOYSTICK_MAXTRESHOLD)
      {
        if(maxNumber > currentMenuNumber)
          currentMenuNumber++;
        else 
          currentMenuNumber = 0;
        
      }
    else
    {
      if (joystickAxisX < JOYSTICK_MINTRESHOLD)
      {
        if(currentMenuNumber > 0)
          currentMenuNumber--;
        else
        currentMenuNumber = maxNumber;
        
      }     
    }
    }
  }
}
void readJoystickValues()// A joystick modul állapotának olvasása
{
  joystickAxisX = 1024-analogRead(JOYSTICK_X);
  joystickAxisY = analogRead(JOYSTICK_Y);
  joystickButtonState = !digitalRead(JOYSTICK_BUTTON);
}
void serialMonitorPrint() // Adatok kikuldese sorosan tesytelés céljából
  { 
    if(millis()-lastTimeSerial > SERIALPRINTINTERVALL)
    {
      lastTimeSerial = millis();
      Serial.println();
      Serial.println(millis());
      Serial.print(F("Kimeneti változók:")); // Az F() szükséges, ugyanis az SRAM korlatozott, es igy a Flash memoriat terheli
      Serial.print(F(" fanState: "));
      Serial.print(fanState);
      Serial.print(F(" irrigationState: "));
      Serial.print(irrigationState);
      Serial.print(F(" sprayState: "));
      Serial.print(sprayState);
      Serial.print(F(" fanState: "));
      Serial.print(fanState);
      Serial.print(F(" lightState: "));
      Serial.println(lightState);
      Serial.println();
      Serial.print(F("Szenzor értékek: "));
      Serial.print(F(" insideTemperature: "));
      Serial.print(insideTemperature);
      Serial.print(F(" outsideTemperature: "));
      Serial.print(outsideTemperature);
      Serial.print(F(" insideHumidity: "));
      Serial.print(insideHumidity);
      Serial.print(F(" outsideHumidity: "));
      Serial.print(outsideHumidity);
      Serial.print(F(" soilMoistureLevel: "));
      Serial.print(soilMoistureLevel);
      Serial.print(F(" lightIntensity: "));
      Serial.println(lightIntensity);
      Serial.println();
      Serial.print(F("Joystick értékek: "));
      Serial.print(F(" joystickAxisX: "));
      Serial.print(joystickAxisX);
      Serial.print(F(" joystickAxisY: "));
      Serial.print(joystickAxisY);
      Serial.print(F(" joystickButtonState: "));
      Serial.println(joystickButtonState);
      Serial.println();
      Serial.print(F("Menu value: "));
      Serial.print(currentMenuNumber);
      Serial.print(F("Submenu value: "));
      Serial.print(currentSubmenuNumber);
      Serial.print(F("isSubmenu: "));
      Serial.print(isSubMenu);
      Serial.println("\n-------------------------------------");
      
    }
    
  }
void killAllDevices()//Minden eszköz OFF-ra állítása, és minden rellélekapcsolása
{
  //az eszkök állapotát off-ra állítani
  fanState = OFF;
  irrigationState = OFF;
  sprayState = OFF;
  heaterState = OFF;
  lightState = OFF;
  //megadni a parancsot a relléknek
  digitalWrite(FANPIN, LOW);
  digitalWrite(IRRIGATIONPIN, LOW);
  digitalWrite(SPRAYPIN, LOW);
  digitalWrite(HEATERPIN, LOW);
  digitalWrite(LIGHTPIN, LOW);
}
void displayInitialize()//Kezdőképernyő mutatása
{
  if(!display.begin(SSD1306_SWITCHCAPVCC, SSD1306_I2C_ADDRESS)) {
    Serial.println(F("SSD1306 allocation failed"));
    for(;;); // Nem sikerült létrehozni a kapcsolatot, végtelen ciklus
  }
  display.clearDisplay();// Clear the buffer

  display.setTextSize(1);      // Szöveg méretének meghatározása
  display.setTextColor(WHITE);
  display.setCursor(0, 0);   // Szöveg pozíciójának megadása
  display.println(F("Kedves Attila Janos"));
  display.println("Github:");
  display.println(F("https://github.com/KedvesAttilaJanos"));
  display.display();
  delay(5000);
  showLoadingScreen();
}
void loaderSwitch(byte loadNum) // A betöltő képernyőnek megfelelően, a setup feladatok végrehalytási sorrendjének meghatározása
{
  switch(loadNum)
  {
    case 30: espSetup(); Serial.println(F("Esp setuped")); break;
    case 50: getIp(); Serial.println(F("Ip get")); break;
    case 60: killAllDevices(); Serial.println(F("Devices off")); break;
    case 70: zeroAllSensor(); Serial.println(F("Sensors Zero")); break;
    case 80: zeroAllInternalVariable(); Serial.println(F("Internal variables zero")); break;
    case 90: readSensor(); Serial.println(F("First read")); break;
  }
}
bool joystickAxisYMoved(String direction) //overload, paraméterként megadható, hogy merre nézze a joystick elmozdulását
{
  if(direction == "right")
    return joystickAxisY > JOYSTICK_MAXTRESHOLD;
  if(direction == "left")
    return joystickAxisY < JOYSTICK_MINTRESHOLD;
}
bool joystickAxisYMoved() // A jobbra/balra történő elmozdulás figyelése
{
  return joystickAxisY < JOYSTICK_MINTRESHOLD || joystickAxisY > JOYSTICK_MAXTRESHOLD;
}
void showLoadingScreen()//Betöltőképernyő megjelenítése
{
  display.clearDisplay();
  display.setTextSize(1);      // Szöveg méretének meghatározása
  display.setTextColor(WHITE);
  display.setCursor(10, 10);   // Szöveg pozíciójának megadása
  display.println(F("Loading..."));
  display.display();
  
  // Animációs betöltési sáv
  for (int i = 0; i <= 100; i += 2) {
    display.fillRect(10, 30, i, 10, WHITE); // Sáv rajzolása
    loaderSwitch(i);
    display.display();
    delay(2); // Sáv frissítési sebessége
  }
  
  // Törlés vagy következő képernyő
  delay(500); 
  display.clearDisplay();
  display.display();
}
void zeroAllSensor()//Minden szenzorérték lenullázása
{
  insideTemperature = 0;
  outsideTemperature = 0;
  insideHumidity = 0;
  outsideHumidity = 0;
  soilMoistureLevel = 0;
  lightIntensity = 0; 
}
void zeroAllInternalVariable()// A belső vátozók alaphelyzetbe állítása
{
  joystickAxisX = 0;
  joystickAxisY = 0;
  joystickButtonState = 0;
  isSubMenu = false;
  currentMenuNumber = 0;
  currentSubmenuNumber = -1;
  lastTimeMenuRefresh = 0;
  maxMenuCount = MAX_MENU_COUNT;
  maxTemp = 0;
  minTemp = 0;
  maxHumidity = 0;
  minHumidity = 0;
  maxMoisture = 0;
  minMoisture = 0;
  minLightLevel = 0;
  languageSet = 0;
  enableSerial = DEBUG;
}
void printCentered(const String &text, int y)// A címek középreigazított kiírása
{
  int textWidth = text.length() * 6; // 6 pixel széles karakterek
  int x = (SCREEN_WIDTH - textWidth) / 2;
  display.setCursor(x, y);
  display.println(text);
}
void changeSelectedMenuVariable()// A kiválasztott értékek megváltoztatása
{
  if(isSubMenu)
  {
    switch (currentMenuNumber)
    {
      case 0:
        if (currentSubmenuNumber == 0) fanState = changeDeviceState(fanState);
        if (currentSubmenuNumber == 1) irrigationState = changeDeviceState(irrigationState);
        if (currentSubmenuNumber == 2) sprayState = changeDeviceState(sprayState);
        if (currentSubmenuNumber == 3) heaterState = changeDeviceState(heaterState);
        if (currentSubmenuNumber == 4) lightState = changeDeviceState(lightState);
      break; 
    }
  }
}
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
void loop() {

  // put your main code here, to run repeatedly:
  readJoystickValues();
  if(enableSerial) //csak akkor küldi ki sorosan az adatokat, ha kap bemenetet sorosan, igy nem vész el foloslegesen erőforrás
    serialMonitorPrint();
  changeMenuNumber(isSubMenu,maxMenuCount);
  mainMenuSystem();
  if(joystickButtonState == true) 
  {
    if(millis()-lastTimeChange > menuChangeIntervall)
    {
      isSubMenu = !isSubMenu;
      maxMenuCount = MAX_MENU_COUNT;
      currentSubmenuNumber = 0;
      lastTimeChange = millis();
    }
      
  }
  //testeljuk le
  transmitDateOnEsp(constructDateString());
  readSensor();
  outRelays();
  display.clearDisplay();
}

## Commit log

2025-04-22 main code aded
    letrehoztuk es hozzaadtuk a repohoz az arduino programot
2025-05-10 readme and files
    hozzáadtam a readme filet és a pcb hez tartozó fileokat
    [Drill_NPTH_Through.DRL, Drill_PTH_Through.DRL, Drill_PTH_Through_Via.DRL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]
2025-05-10 readme actualized
    [GreenhouseController v2.stl]
